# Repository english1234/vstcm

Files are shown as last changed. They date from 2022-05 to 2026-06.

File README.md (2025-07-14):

# VSTCM - the v.st Colour Mod - a colour vector graphics generator
The vstcm is a vector signal transceiver PCB which generates colour vector graphics to be displayed on an oscilloscope or vector monitor such as Amplifone, Wells Gardner WG6100, Hantarex MTRV and Electrohome G05, as used in Star Wars, Tempest, Gravitar, etc. 

When used with a computer (Raspberry Pi, PC, ...) running AdvanceMAME, it can be used to play classic colour (and monochrome) vector arcade games, but it can also play certain games all by itself using various emulators. If you search for vstcm on a well-known video sharing site you can see the board in action.

(Haven't got a vector monitor or an oscilloscope? Make your own, it's not that hard! - see below).

For those who built a V2 of this board, a document is provided to convert the wiring to run with V3 software.

vstcm pcb

starwars

The original v.st was designed by Trammell Hudson for black & white games. Documentation for that version can be found here https://github.com/osresearch/vst and here https://trmm.net/V.st/

Compared to the original version, the new vstcm adds:
- RGB colour with different intensity levels
- 6502, Z80 and 6809 emulators which allows it to play games on its own without a Raspberry Pi or MAME
- A mini version of MAME for playing vector games on the Teensy without a Raspberry Pi
- An upgrade to the Teensy 4.1 for more power (eg >800Mhz as opposed to 120Mhz for the Teensy 3.2)
- Asteroids style test patterns in Red, Green & Blue to aid CRT convergence
- A configuration menu with settings stored on the built in SD card
- Programmable onboard control buttons
- Programmable IR remote control buttons
- Extra pots to control X & Y position (to complement the existing X & Y size pots)
- Several power supply options: either USB, or external 5V/9V/12V

testscreen1

The board was built with simplicity in mind using components that are easy to find, and easy to solder so that anyone can build one.

## Programme code

Currently, the board can work in either of two ways:
- connected to a Raspberry Pi running MAME. The programme code for this option is a development of that which was provided with the original version of the v.st, with modifications made by "Swapfile" (Github user) to interface with AdvanceMAME, and then further modifications made by myself in order to add the new functionality specific to the vstcm, followed by extensive optimisation by fcawth (cf his fork of this project). There is scope for further improvement (see the wiki for this project in the link above), and it is hoped that the publication on github will encourage contributions to develop this as a relatively cheap and easy solution for the vector arcade / vector graphics community.
- on its own, running a 6502, Z80 or 6809 emulator, and with the original game ROM files stored on the SD card of the Teensy. So far, Battlezone, Asteroids and Donkey Kong work with this, but it shouldn't be too much trouble to get others working. Sound and external controls have not been properly implemented as yet (please feel free to contribute the necessary mods to the code...). See instructions below for how to get this to work.

## History of development

For those interested in seeing how things got to this point, the inital development of the PCB was documented with plenty of pictures (in French, but use Google Translate if required) here : https://www.gamoover.net/Forums/index.php?topic=43469.0 (from page 5) and also shows previous work on building vector arcade HV boards, an Amplifone deflection reproduction, an Asteroids game PCB reproduction, a bit of yoke rewinding, etc.

If you want to get in touch to ask questions, or contribute, I can be contacted at: robin@robinchampion.com or on Github (user english1234), Gamoover (english2), UKVAC (english2), KLOV (english2), as well as via the various vector graphics/Vectrex forums on Facebook.

A dedicated vstcm web page can be found here: https://robinchampion.com/vst_colour_mod.htm

Thread on KLOV: https://forums.arcade-museum.com/threads/announcing-the-vstcm-colour-vector-generator.505940/

Thread on UKVAC: http://www.ukvac.com/forum/announcing-the-vstcm-colour-vector-generator_topic388998_page1.html

## Getting the PCB built

A ZIP file is in the Gerbers directory. This can be uploaded to your PCB manufacturer of choice. It's a 2 sided 10cm x 10cm board so should be extremely cheap (JLPCB charged less than 5€ / $5 + shipping for 10 pieces in May 2022).

## Components

The BOM is in a dedicated folder and has Mouser references for many parts at the right hand side. 

- IC2: You need to choose if you are going to use an external supply or not and if so what voltage to use (5V, 9V or 12V). Recom makes these parts, but so do Traco and there may be other brands. Make sure there is a D (for double) at the end of the model number which generates +/- voltages, rather than the S (single) version. See power options below.
- The Molex parts are not strictly necessary, you may prefer something different or simply to solder wires directly to the holes in the PCB.
- U5: See power options below. I have also used a 7805 as a direct replacement with a small heatsink on it, which gets quite warm but hasn't burnt out as yet.
- optional IR remote: I really recommend this if you are putting the board inside a cabinet - see "IR remote programmable control buttons" below.
 
I would recommend socketing everything on the board (Teensy, DACs, Op Amps) so that they can be swapped out if better choices are found in the future.

Make sure you order short resistors, space for them on the board is tight.

## Power options for the PCB

The PCB can be powered in several ways (connect to J6):

|N° | Power supply option | Supplies | C3/C4 | IC2 | U5/C19/C20  | Split pad Teensy | Tested |
|---|---|---|---|---|---|---|---|
| 1 | USB 5V | Complete circuit inc Teensy | Required | RB-0512D | Absent | No | No |
| 2 | USB 5V + external 5V unregulated | USB supplies Teensy, external supplies rest | Required | RB-0512D | Absent | No | Yes |
| 3 | External 9V unregulated | Complete circuit inc Teensy | Required | RB-0912D | Present | Yes | No |
| 4 | External 12V unregulated | Complete circuit inc Teensy | Required | RB-1212D | Present | Yes | Yes |
| 5 | USB 5V + external 12V regulated  | USB supplies Teensy, external supplies rest | Absent | Absent | Absent | No | Yes |

1/ power the whole thing via USB from a Raspberry Pi: This requires a short good quality USB cable to work reliably. Make sure the Pi has at least a 3A supply. Since U5 is absent, bridge the two outer pins with a jumper wire.

2/ power the Teensy via USB from a Raspberry Pi, and use a separate external supply (such as a wall wart) for the DACs and Op Amps. 

3 & 4/ power the whole thing via an external supply which can be 9V or 12V (not 5V): this requires adding a LM2940T-5.0 regulator at U5 along with it's associated caps at C19 & C20, as well as cutting a link on the Teensy to ensure that it doesn't receive conflicting power from both the USB and the external supply. The RB-xx12D needs to be either a 9V or 12V model depending on the voltage of the external supply. A 5V supply won't work as the LM2940 requires over 6V to function according to its datasheet. 

The choice is really just a matter of what you have on hand. It makes no difference what vector CRT you have, as the output voltages of the PCB are the same whatever you use to power it. If you're connecting to an existing arcade machine, then chances are you have a +/-12V supply coming out of the power brick. Otherwise, many people have a box of old "wall wart" 5V (or 9V or 12V) adapters which will work fine: either fit a barrel connector to the PCB input or chop the connector off the end of the power supply and solder the 2 wires directly to the board (check with a multimeter first which is positive and which is ground). 

The easiest option is to use a 5V (option 2) as the LM2940 is not required, and you don't need to cut the link on the Teensy to separate USB and external power.
Do not use J7 unless you have thoroughly understood how the schematic works for the power supply.

## Schematic

This may seem obvious, but it's worth downloading Kicad in order to view the schematic and the PCB as there are some build notes on the schematic, and it will help you to understand the main sections of the PCB and how it all connects together. For the lazier, a PDF is available.

## Programming the Teensy

Follow the instructions on this page to download and install the Arduino environment and Teensyduino extension: https://www.pjrc.com/teensy/td_download.html
Use the Arduino software to load the .ino file in the Teensy code directory.

Connect the Teensy via USB to your computer.

Choose the Teensy 4.1 in the Teensyduino options, and overclock to 816Mhz, as well as the "Fastest" option. Make sure you have the latest version of Teensyduino.

Press the compile button. You may need to add the Bounce2 library if you don't already have it.

Press the upload button (or the button on the Teensy if it doesn't upload automatically).

(You can also use PlatformIO if you prefer).

There is a more detailed guide "How to programme the Teensy with the code for the VSTCM PCB.pdf" in the root directory.

## Testing the vstcm

Once the board is built and the Teensy programmed and fitted, it can be connected to your deflection board of choice (it has been tested on Amplifone, Wells Gardner WG6100, Electrohome G05 and Hantarex MTRV so far) and when powered on should show a test screen. It may be necessary to change the size and positions pots on the PCB as well as other controls on the deflection board (such as Z or colour gain).

Before connecting to the deflection board, it would probably be a good idea to make sure the vstcm is generating appropriate voltages at its outputs (preferably with an oscilloscope, or failing that with a decent multimeter). 

If you want to save changes to settings shown on the onscreen menu, then put a SD card in the Teensy (formatted with FAT32). After changing the settings to your requirements and pressing the middle button on the PCB, the vstcm.ini file will be created at the root of the SD card so that they can be reloaded at each boot. 

typicalsetup

## Testing Battlezone with the 6502 emulator

Put the following ROM files on a SD card in a directory called roms/Battlezone: 036414a.01, 036413.01, 036412.01, 036411.01, 036410.01, 036409.01, 036422.01, 036421.01 (it's up to you to find them from somewhere...).

Put the SD card in the slot on the Teensy.

Upload the bzone.ino to the vstcm using the Arduino software.

Plug it in.

Switch on! 

If you have a IR remote then you can control the game in a rather basic manner for the moment... (press OK to start)

## Testing games with AdvanceMAME

A Raspberry Pi 4 or 400 is recommended (I have also tested with a Pi 3 Model B+ 2017 and an Orange Pi 3 LTS which seem to work ok too). If you are running the vstcm from the Raspberry/Orange Pi then a 3A supply would be preferable.
Other options are Windows, a Linux VM under Windows, native Linux or Mac (the latter of which I have not yet tested). 
I followed the instructions here to download and compile AdvanceMAME: https://www.arcade-projects.com/threads/almost-pixel-perfect-arcade-emulation-on-raspberry-pi-with-advancemame.7777/

orangepi

Basically, there are just 7 commands on the Pi which are as follows:

```sudo apt-get install git autoconf automake libsdl2-dev libasound2-dev libfreetype6-dev zlib1g-dev libexpat1-dev libslang2-dev libncurses5-dev

git clone https://github.com/amadvance/advancemame.git

cd advancemame

sh autogen.sh

./configure

make -j3

sudo make install
```

You need to find some ROMs from somewhere and copy them into the ROM folder. I'm sure you'll manage to find them... The easiest way to get them on to the Pi is to set up a Samba share and copy them over from a PC.

Then to launch, type advmame followed by the name of the game.

If you're not getting output over the USB cable to the vstcm, then check the advmame.rc file and at the bottom make sure you have vector_aux_renderer set to dvg (instead of none) and vector_aux_renderer_port set to /dev/ttyACM0

gravitartempest

The AdvanceMAME protocol for the USB DVG is here: https://github.com/amadvance/advancemame/blob/master/advance/osd/dvg.c 

You can change the settings on the VSTCM during a game by pressing the left and right buttons on the PCB simultaneously to display the menu as an overlay.

## IR remote programmable control buttons

For £1 / $1 / 1€ you can get a HX1838 infra red adapter board with remote control, wiring, everything you need in fact. There are only 3 wires to connect: 5V, GND and signal. I soldered pin headers in the holes provided on either side of the Teensy, and put 5V on the bottom left hand hole of the Teensy (to left of USB socket), GND on the bottom right pin of the Teensy, and signal on pin 32 (top right hand pin of Teensy). 

This might seem like a bit of a gadget, but when you are spending your time going behind the arcade cab to press a button, coming back round the front to see the effect on the screen, and doing this over and over again, the advantages become obvious! 

The IR sensor is the size of an LED and so very easy to hide somewhere at the front of an arcade cab, and then you can just change the settings at will while you look at the screen.

IR1ir2

## Haven't got a vector monitor or an oscilloscope?

Apart from this PCB, you need a CRT, a high voltage board, a deflection board and a power supply to make a complete vector monitor. There are solutions for all of these parts:

CRT - I'm using a 19"/48cm Philips TV bought for pennies through the small ads. You need to rewind the yoke using magnet wire. There is an excellent video by Jason Kopp here which explains all: https://youtu.be/Ci9qiGVMF7s I experimented on a 5" b&w security monitor first, then went for the big screen. Avoid Trinitrons and PC monitors, you need a basic no frills TV tube. It took me several attempts to get it more or less right, but I still have some wires which are not completely straight and the result seems to be the slightly bent vectors visible in the top right hand corner of my screen in the photo of the test screen above. The whole thing really wasn't hard, it just requires patience.

High voltage: Amplifone and Wells Gardner 6100 blank PCBs are available online, and there are also fully built solutions (see the various vector groups on Facebook) available new or second hand from the usual auction sites and specialist arcade sellers (mostly USA based).

Deflection board: I bought a second hand non working Amplifone and then fixed it (which wasn't hard, plenty of info online), but new PCBs are available online, and a Wells Gardner WG6100 should work too.

Power supply: the CRT and deflection board can be run either from an old Atari power brick, or else by wiring together two cheap 24V power supplies from Aliexpress in order to provide +/- 24V which satisfies the requirement for 50VAC on a Amplifone colour vector monitor. The CRT needs 6.3V for the heater filament, which I'm getting from an Atari power brick using the supply meant for the coin door, but there are other solutions if you look online (hint: 6.3V is frequently required for valve amp projects). If you find the right Atari power brick, it will power the whole thing: CRT, HV, deflection, Raspberry Pi and vstcm.

There's plenty of discussion of solutions to these problems on KLOV, UKVAC, and the FB vector forums with plenty of knowledgeable people able to answer questions. Also there are a fair few videos on Youtube going from theory to practice. Again, it's not that hard, so give it a go!

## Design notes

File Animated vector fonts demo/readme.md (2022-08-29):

Found this here: https://forum.pjrc.com/threads/45016-Vector-Font-library-for-Teensy-3-6

and associated video showing the code running on a LCD here: https://youtu.be/T0WgGcm7ujM

and adapted it for the VSTCM V3.0

here it is running on a vector monitor using the vstcm and Teensy 4.1 https://youtu.be/WIkLRix-tPs

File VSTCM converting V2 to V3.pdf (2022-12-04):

# VSTCM

# Converting PCB V2 to V3

Several improvements have been made in the change from VSTCM V2 to V3, in order to increase performance and improve image quality.

One of the changes made for much improved performance is a modification of the DAC outputs. This change means that code developed for V3 no longer works on V2 and vice versa. However, it is easy to implement the change on a V2 PCB.

To convert the DAC outputs of a PCB V2, two tracks need to be cut, and two patch wires added.

The third difference (X & Y outputs swapped) can be changed in the VSTCM settings (Swap XY).

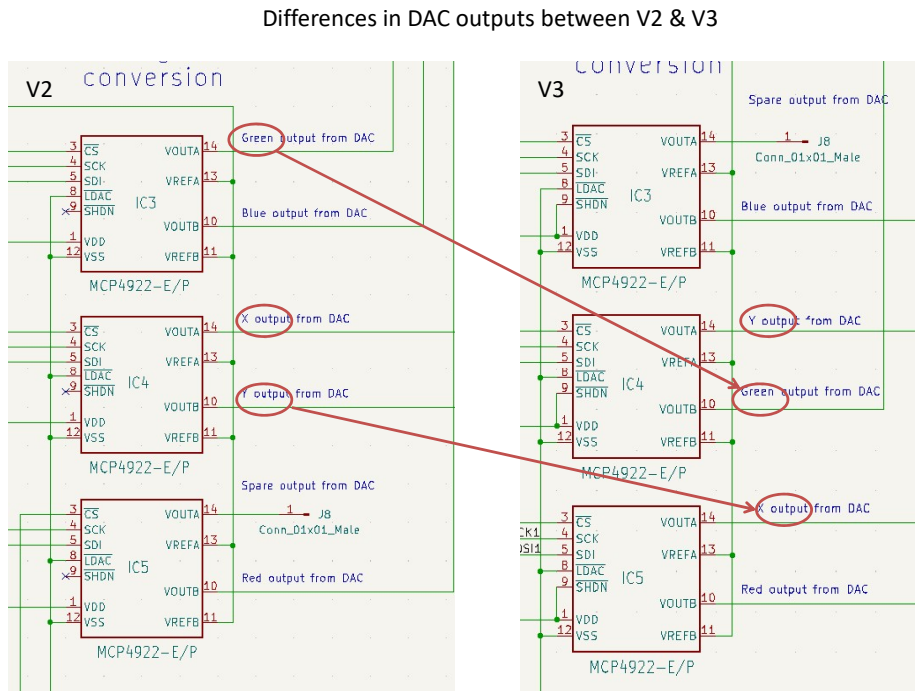
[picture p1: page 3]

Differences in DAC outputs between V2 & V3

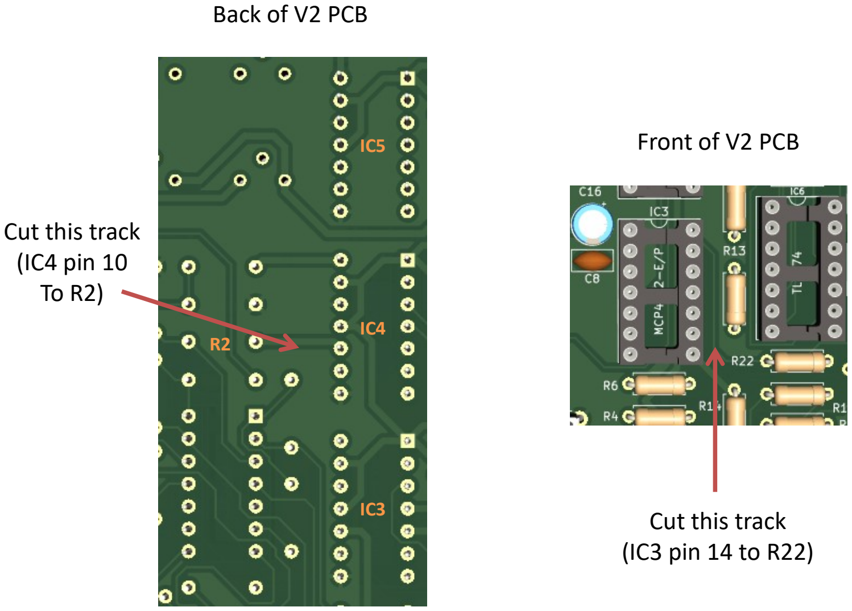
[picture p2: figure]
Back of V2 PCB; Front of V2 PCB; Cut this track (IC4 pin 10 To R2); Cut this track (IC3 pin 14 to R22)

Back of V2 PCB

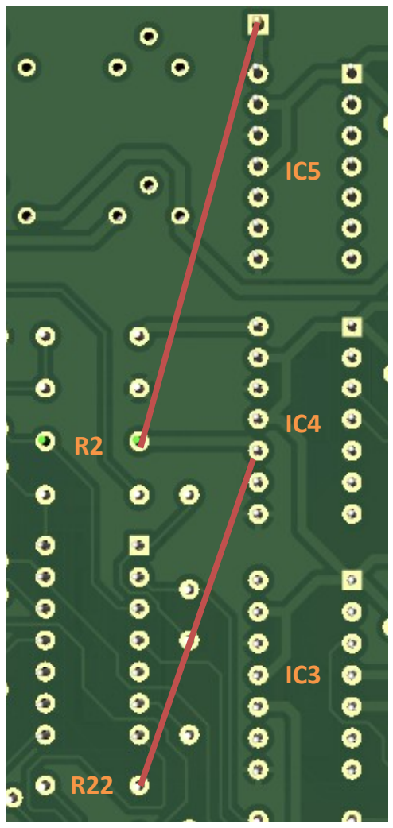
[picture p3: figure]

Add patch wire from
J8 to R2

Add patch wire from
IC4 pin 10 to R22

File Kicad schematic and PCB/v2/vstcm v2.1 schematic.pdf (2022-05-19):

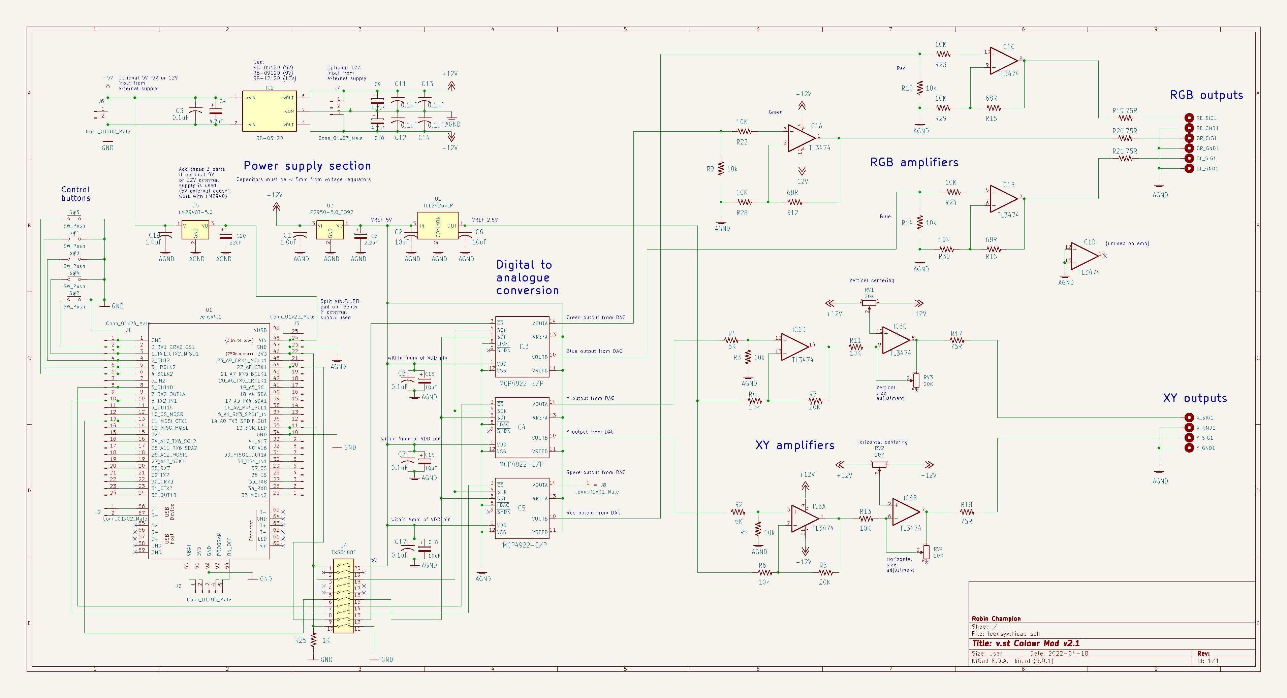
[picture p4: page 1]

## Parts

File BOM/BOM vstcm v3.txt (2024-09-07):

| Ref | Qty  | Value | Component name | Footprint | Mouser Ref | 
| --- | ---- | --- | --- | --- | --- |
| C1, C19 (optional) |  2 | 1.0uF 50v CER | C-US025-024X044 | Capacitor_THT:C_Disc_D5.0mm_W2.5mm_P2.50mm | C420C105K5R5TA7200 | 
| C2, C6, C27 |  3 | 10uF 25V CER | C-US025-024X044 | Capacitor_THT:C_Disc_D5.0mm_W2.5mm_P2.50mm | FG26X7R1E106KRT06 | 
| C22, C12, C7, C24, C3, C17, C23, C21 | | | | | |
| C26, C13, C8, C25, C11, C14 | 14 | 0.1uF 50V CER | C-US025-024X044 | Capacitor_THT:C_Disc_D5.0mm_W2.5mm_P2.50mm | C410C104Z5U5TA7200 | 
| C4, C9, C10 |  3 | 4.7uF50V | CP_Radial_D5.0mm_P2.00mm | Polarized capacitor | ESH475M050AC3AA | 
| C5 |  1 | 2.2uF 50V | CP_Radial_D5.0mm_P2.00mm | Polarized capacitor | ESH225M050AC3AA | 
| C15, C16, C18 |  3 | 10uF 50V | CP_Radial_D5.0mm_P2.00mm | Polarized capacitor | ESH106M050AC3AA | 
| C20 (optional) |  1 | 22uF 50V | CP_Radial_D5.0mm_P2.00mm | Polarized capacitor | ESH226M050AC3AA |
| IC1, IC6 |  2 | TL3474 | QUAD_OPAMPP | DIP-14_W7.62mm_Socket | TL3474IN | 
| IC2 |  1 | 5VDC | DC/DC CONVERTER +/-5V 1W | RECOM / Traco | RB-0512D | 
| IC2 (optional) |  1 | 9VDC | DC/DC CONVERTER +/-12V 1W| RECOM / Traco | RB-0912D | 
| IC2 (optional) |  1 | 12VDC | DC/DC CONVERTER +/-12V 1W| RECOM / Traco | RB-1212D | 
| IC3, IC4, IC5 |  3 | MCP4922-E/P | MCP4922-E/P | DIP-14_W7.62mm_Socket | MCP4922-E/P | 
| J1 |  1 | Conn_01x24_Male | Conn_01x24_Male | Generic connector, single row, 01x24 | | 
| J2 |  1 | Conn_01x05_Male | Conn_01x05_Male | Connector_PinHeader_2.54mm:PinHeader_1x05_P2.54mm_Vertical | | 
| J3 |  1 | Conn_01x25_Male | Conn_01x25_Male | Generic connector, single row, 01x25Aliexpress | | 
| J5 |  1 | Conn_01x06_Male | Conn_01x06_Male | Connector_PinHeader_2.54mm:PinHeader_1x06_P2.54mm_Vertical | | 
| J6 |  1 | Conn_01x02_Male | Conn_01x02_Male | Molex 22-27-2021Generic connector, single row, 01x02 | 22-27-2021 | 
| | | | | Molex 10-11-20232 pin plug connector for 22-27-2021 | 10-11-2023 | 
| J7 |  1 | Conn_01x03_Male | Conn_01x03_Male | Molex 38-00-6293Generic connector, single row, 01x03 | 38-00-6293 | 
| |  1 | | | Molex 22-01-20373 pin plug connector for 38-00-6293 | 22-01-2037 | 
| | | | | Pins for Molex connectors series 7879 | | 
| J8 |  1 | Conn_01x01_Male | Conn_01x01_Male | Connector_PinHeader_2.54mm:PinHeader_1x01_P2.54mm_Vertical | | 
| J9 |  1 | Conn_01x02_Male | Conn_01x02_Male | Generic connector, single row, 01x02Aliexpress | | 
| TP1, TP3, TP2 |  3 | Conn_01x01_Male | Conn_01x01_Male | Connector_PinHeader_2.54mm:PinHeader_1x01_P2.54mm_Vertical | | 
| R11, R13 |  2 | 5K 1% 1/4W | R-US_0204/2V | Resistor_THT:R_Axial_DIN0207_L6.3mm_D2.5mm_P7.62mm_Horizontal | 603-CFR25SJT-52-5K |
| R4, R5, R25, R14, R3, R26, R9, R6, R10 | | | | | |
| R23, R24, R8, R27, R29, R7, R22, R31 | | | | | |
| R28, R30 | 19 | 10K 1% 1/4W | R-US_0204/2V | Resistor_THT:R_Axial_DIN0207_L6.3mm_D2.5mm_P7.62mm_Horizontal | 71-RN60E1002F |
| R12, R15, R16 |  3 | 15K 1% 1/4W | R-US_0204/2V | Resistor_THT:R_Axial_DIN0207_L6.3mm_D2.5mm_P7.62mm_Horizontal | 71-CCF5515K0FKE36 |
| R17, R18, R19, R20, R21 |  5 | 75R 5% 1/4W CARB| R-US_0204/7 | Resistor_THT:R_Axial_DIN0207_L6.3mm_D2.5mm_P7.62mm_Horizontal | CFR-25JB-52-75R | 
| R1, R2 |  2 | 1K 1/3W 5% CARB | R-US_0204/2V | Resistor_THT:R_Axial_DIN0207_L6.3mm_D2.5mm_P7.62mm_Horizontal | CFR25J1K0 | 
| RV1, RV2, RV3, RV4 |  4 | 20K | R_Potentiometer | Potentiometer_THT:Potentiometer_Bourns_3386P_Vertical | 3386P-1-203LF | 
| SW1, SW2, SW3, SW4, SW5 |  5 | SW_Push | SW_Push | SW_PUSH_6mm_H4.3mm Push button switch, generic, two pins | TS02-66-80-BK-100-SCR-D | 
| U1 |  1 | Teensy4.1 | | | DEV-16771 | 
| U3 |  1 | LP2950-3.3_TO92 | LP2950-3.3_TO92 | Micropower Voltage Reg with Shutdown 100mA Fixed Output 3.3V  | 926-2950CZ-3.3/NOPB | 
| U5 (optional) |  1 | LM2940T-5.0 | | REG LINEAR 5V 1A TO220-3 | | 
| L1 |  1 | 0R | Wire link | | |
| Optional |  1 | HX1838 | | IR Remote control and sensor | Aliexpress |
| BL_GND1, Y_GND1, RE_SIG1, RE_GND1 | | | | | |
| Y_SIG1, BL_SIG1, GR_SIG1, X_SIG1 | | | | | |
| GR_GND1,X_GND1 |  2 | .156 SPOX | 5 pin male Molex | Molex connector 09-65-2058 (or use 1x10 pin) | 538-09-65-2058 |
| Teensy 4.1 |  1 | | | Attach pin headers to plug into PCB | Various sources |
| IC sockets |  5 | | | DIP 14 pitch 2.54mm, row spacing 7.62mm | 571-1-2199298-3 |
| Mounting for Teensy | | | | Use breakable 40 pin headers and sockets | Aliexpress |

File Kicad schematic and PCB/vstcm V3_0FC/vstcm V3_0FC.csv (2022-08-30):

Id | Designator | Package | Quantity | Designation | Supplier and ref
1 | BL_GND1,Y_GND1,RE_SIG1,RE_GND1,Y_SIG1,BL_SIG1,GR_SIG1,X_SIG1,GR_GND1,X_GND1 | Molex156Pin | 10 | MountingHole_Pad
2 | IC4,IC3,IC5 | DIP-14_W7.62mm_Socket | 3 | MCP4922-E/P
3 | U5 | TO-220-3_Vertical | 1 | LM2940T-5.0
4 | R15,R16,R12 | R_Axial_DIN0207_L6.3mm_D2.5mm_P7.62mm_Horizontal | 3 | 15K
5 | SW2,SW4,SW5,SW1,SW3 | SW_PUSH_6mm_H4.3mm | 5 | SW_Push
6 | R21,R17,R20,R19,R18 | R_Axial_DIN0207_L6.3mm_D2.5mm_P7.62mm_Horizontal | 5 | 75R
7 | RV1,RV4,RV3,RV2 | Potentiometer_Bourns_3386P_Vertical | 4 | 20K
8 | R4,R5,R25,R14,R3,R26,R9,R6,R10 | R_Axial_DIN0207_L6.3mm_D2.5mm_P7.62mm_Horizontal | 9 | 10k
9 | C18,C15,C16 | CP_Radial_D5.0mm_P2.00mm | 3 | 10uF
10 | C22,C12,C7,C24,C3,C17,C23,C21,C26,C13,C8,C25,C11,C14 | C_Disc_D5.0mm_W2.5mm_P2.50mm | 14 | 0.1uF
11 | R24,R23,R8,R27,R29,R7,R22,R31,R28,R30 | R_Axial_DIN0207_L6.3mm_D2.5mm_P7.62mm_Horizontal | 10 | 10K
12 | R11,R13 | R_Axial_DIN0207_L6.3mm_D2.5mm_P7.62mm_Horizontal | 2 | 5K
13 | C2,C27,C6 | C_Disc_D5.0mm_W2.5mm_P2.50mm | 3 | 10uF
14 | C4,C10,C9 | CP_Radial_D5.0mm_P2.00mm | 3 | 4.7uF
15 | TP1,TP3,J8,TP2 | PinHeader_1x01_P2.54mm_Vertical | 4 | Conn_01x01_Male
16 | C20 | CP_Radial_D5.0mm_P2.00mm | 1 | 22uF
17 | J7 | Molex_KK-254_AE-6410-03A_1x03_P2.54mm_Vertical | 1 | Conn_01x03_Male
18 | IC1,IC6 | DIP-14_W7.62mm_Socket | 2 | TL3474
19 | J1 | PinHeader_1x24_P2.54mm_Vertical | 1 | Conn_01x24_Male
20 | J9 | PinHeader_1x02_P2.54mm_Vertical | 1 | Conn_01x02_Male
21 | R1,R2 | R_Axial_DIN0207_L6.3mm_D2.5mm_P7.62mm_Horizontal | 2 | 1K
22 | C5 | CP_Radial_D5.0mm_P2.00mm | 1 | 2.2uF
23 | J6 | Molex_KK-254_AE-6410-02A_1x02_P2.54mm_Vertical | 1 | Conn_01x02_Male
24 | U3 | TO-92 | 1 | LP2950-3_3_TO92
25 | C1,C19 | C_Disc_D5.0mm_W2.5mm_P2.50mm | 2 | 1.0uF
26 | J3 | PinHeader_1x25_P2.54mm_Vertical | 1 | Conn_01x25_Male
27 | L1 | L_Axial_L12.0mm_D5.0mm_P15.24mm_Horizontal_Fastron_MISC | 1 | L
28 | U1 | Teensy41 | 1 | Teensy4.1
29 | IC2 | RECOM_0512D | 1 | RB-0512D
30 | J2 | PinHeader_1x05_P2.54mm_Vertical | 1 | Conn_01x05_Male

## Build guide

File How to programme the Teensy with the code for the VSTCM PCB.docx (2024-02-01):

How to programme the Teensy with the code for the VSTCM PCB

1/ Download the code from Github and unzip it.

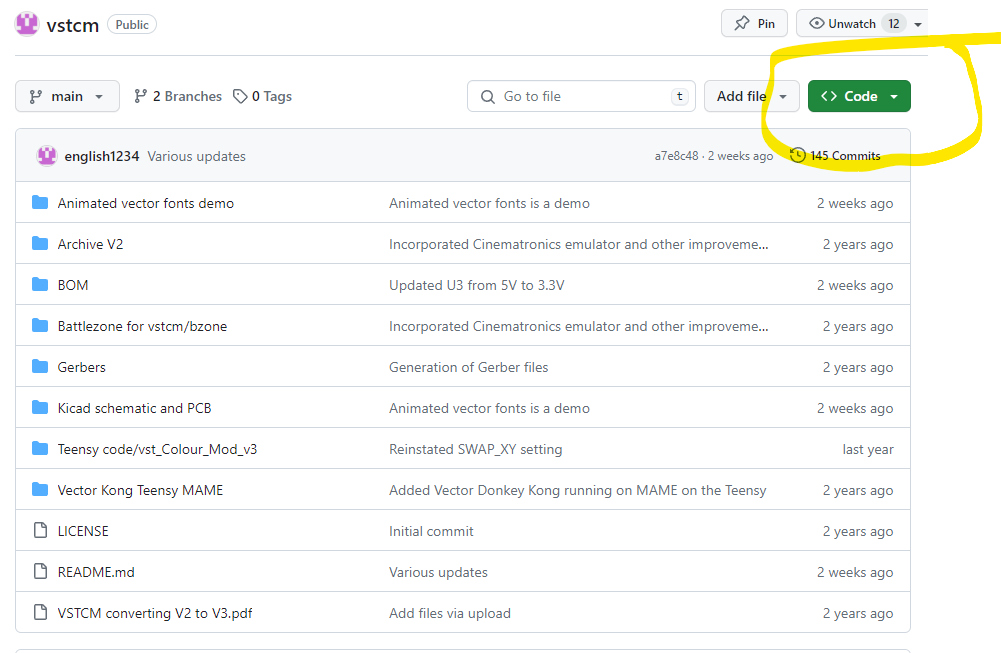
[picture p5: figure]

2/ Open Arduino IDE

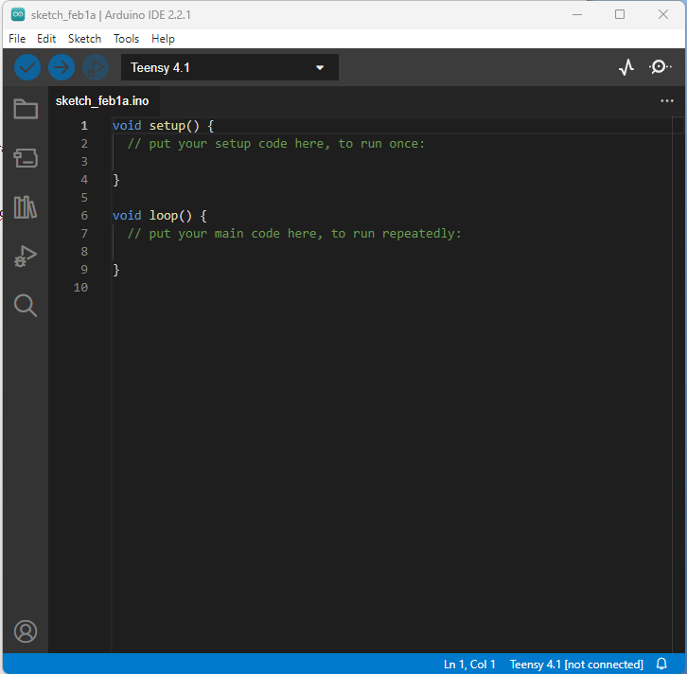
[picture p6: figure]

Open vst_Colour_Mod_v3 .ino (File->Open…) in the Teensy code directory of the unzipped directory.

Make sure the Teensy 4.1 board is selected, and set the code to “Fastest” and 816Mhz.

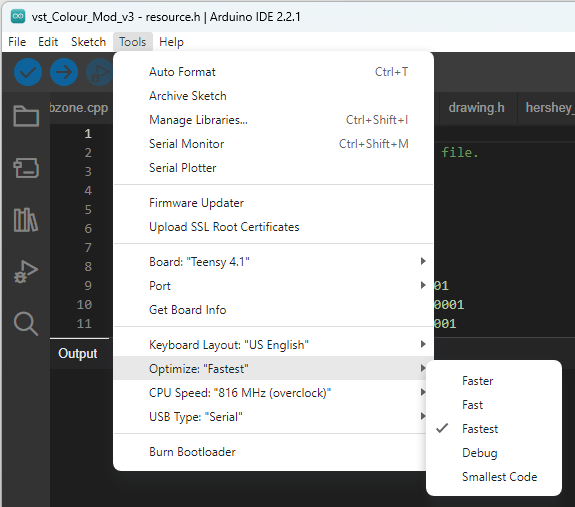
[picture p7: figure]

Connect the Teensy with a USB cable to the PC. Press the blue circle with a tick (check) to compile the sketch.

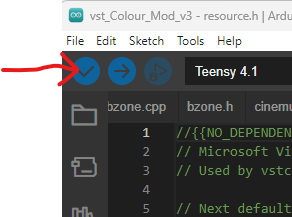
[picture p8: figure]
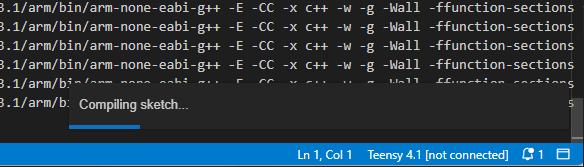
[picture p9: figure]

If the sketch compiles correctly (there might be missing libraries to sort out), the following screen should appear (it may be an icon on the task bar)

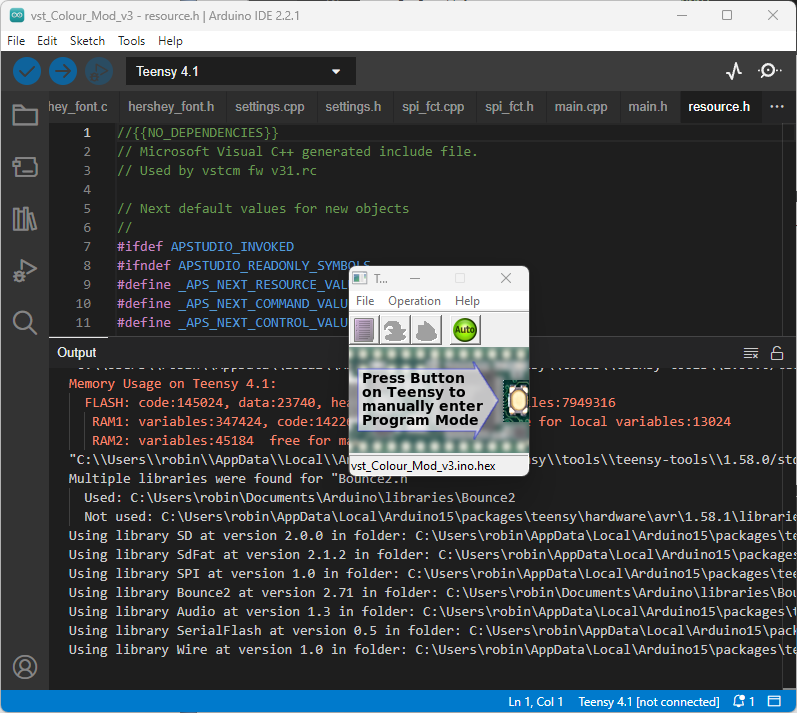
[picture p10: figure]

Press the white button on the Teensy to upload the code. It is now programmed and can be disconnected and is ready for use.

Once the VSTCM is powered up and connected to a vector monitor or oscilloscope, the menu screen should display.

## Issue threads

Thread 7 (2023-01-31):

L1 purpose?

pashdown, 2023-01-31:
L1 is marked as optional on the BOM, but there is no documentation as to why, or how the value is calculated (100uF / 220uF).  Can someone clarify this?

english1234, 2023-01-31:
It was added as an experiment on the v3 by @fcawth, but it had no visible effect as far as I'm aware, so can be left out: just bridge it with wire.

Closed 2023-04-04.

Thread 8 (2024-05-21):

Pincushion and linearity

smdjeff, 2024-05-21:
https://github.com/english1234/vstcm/blob/8db37865ba3121a6b98a831275f08750b0315600/Teensy%20code/vst_Colour_Mod_v3/drawing.cpp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

Some vector games have linearity and pincushion in the deflection board, some are on the game boards.

Consider adding linearity.
Consider making them adjustable values, not just on / off.

english1234, 2024-05-21:
Thanks for the suggestion Jeff, I've added it to the wiki which contains ideas for future versions. If you want to incorporate the changes yourself, then I'd be happy to integrate them.

Closed 2024-05-21.

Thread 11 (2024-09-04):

Divide power connector requirements, L1, add sockets, and female molex on BOM

pashdown, 2024-09-04:
It is somewhat unclear as to what components are required for what style of power inputs, could this be clarified?  L1 shows a resistor, which I presume is used instead of IR, what is it? Could the sockets for the ICs and Teensy be on the BOM, along with the female molex connector that matches 09-65-2058?

pashdown, 2024-09-06:
Thank you for doing this.  My confusion on the sockets is that Mouser seems to have a billion different types of DIP 14 and I don't know what the spec is for the Teensy.

english1234, 2024-09-07:
For DIP 14 the requirement is pitch of 2.54mm and row spacing of 7.62mm. I have updated the BOM with suggested Mouser references. For the Teensy I just used pin headers and sockets, which you can buy in breakable strips of 40 pins. Mouser ones seem very expensive, I get them in packs from Aliex or Amazon.

Closed 2024-11-11.

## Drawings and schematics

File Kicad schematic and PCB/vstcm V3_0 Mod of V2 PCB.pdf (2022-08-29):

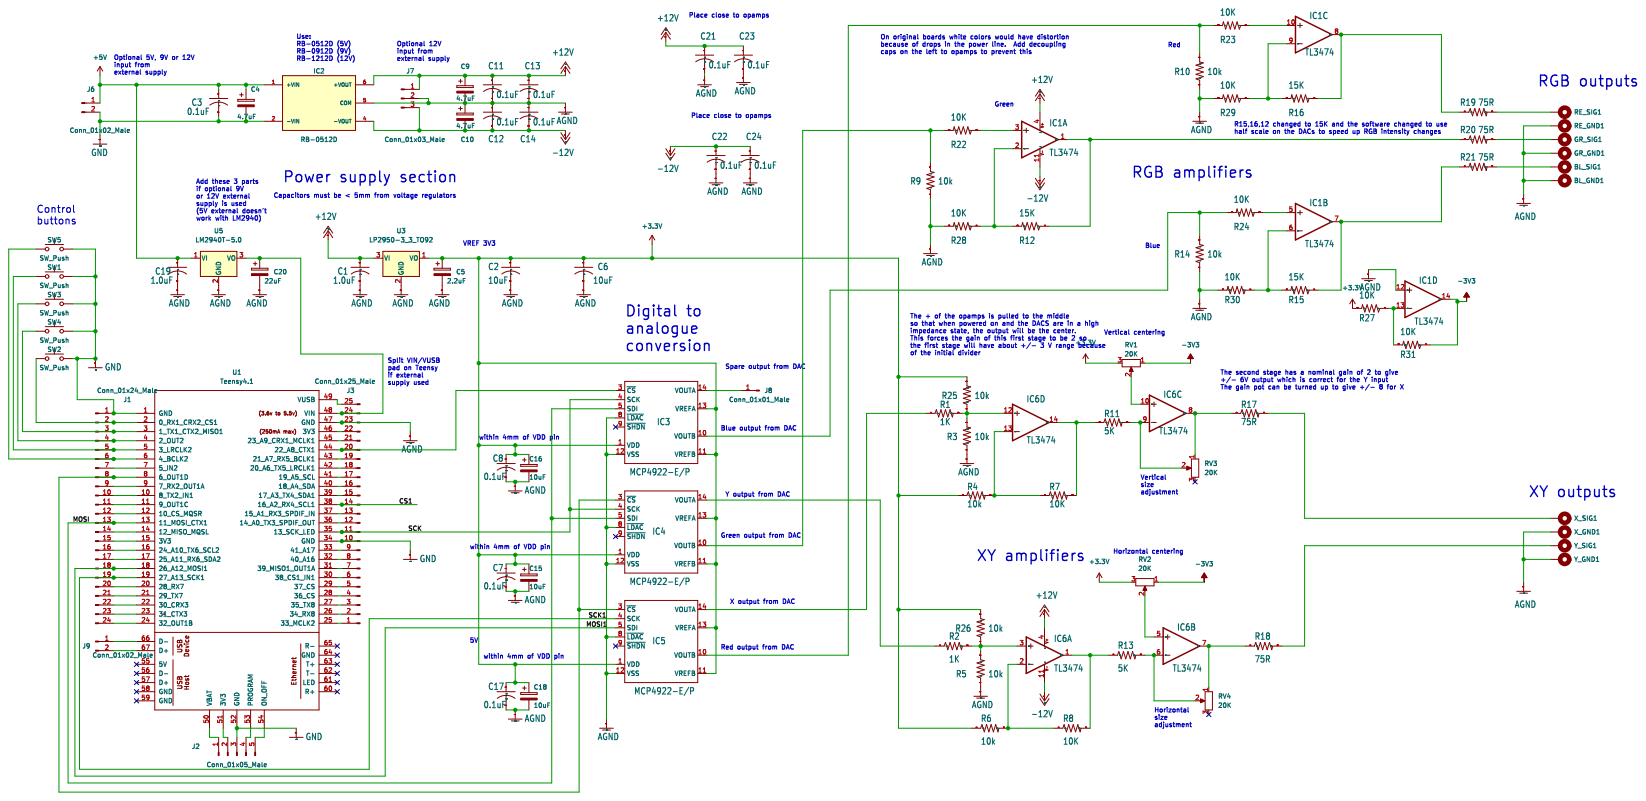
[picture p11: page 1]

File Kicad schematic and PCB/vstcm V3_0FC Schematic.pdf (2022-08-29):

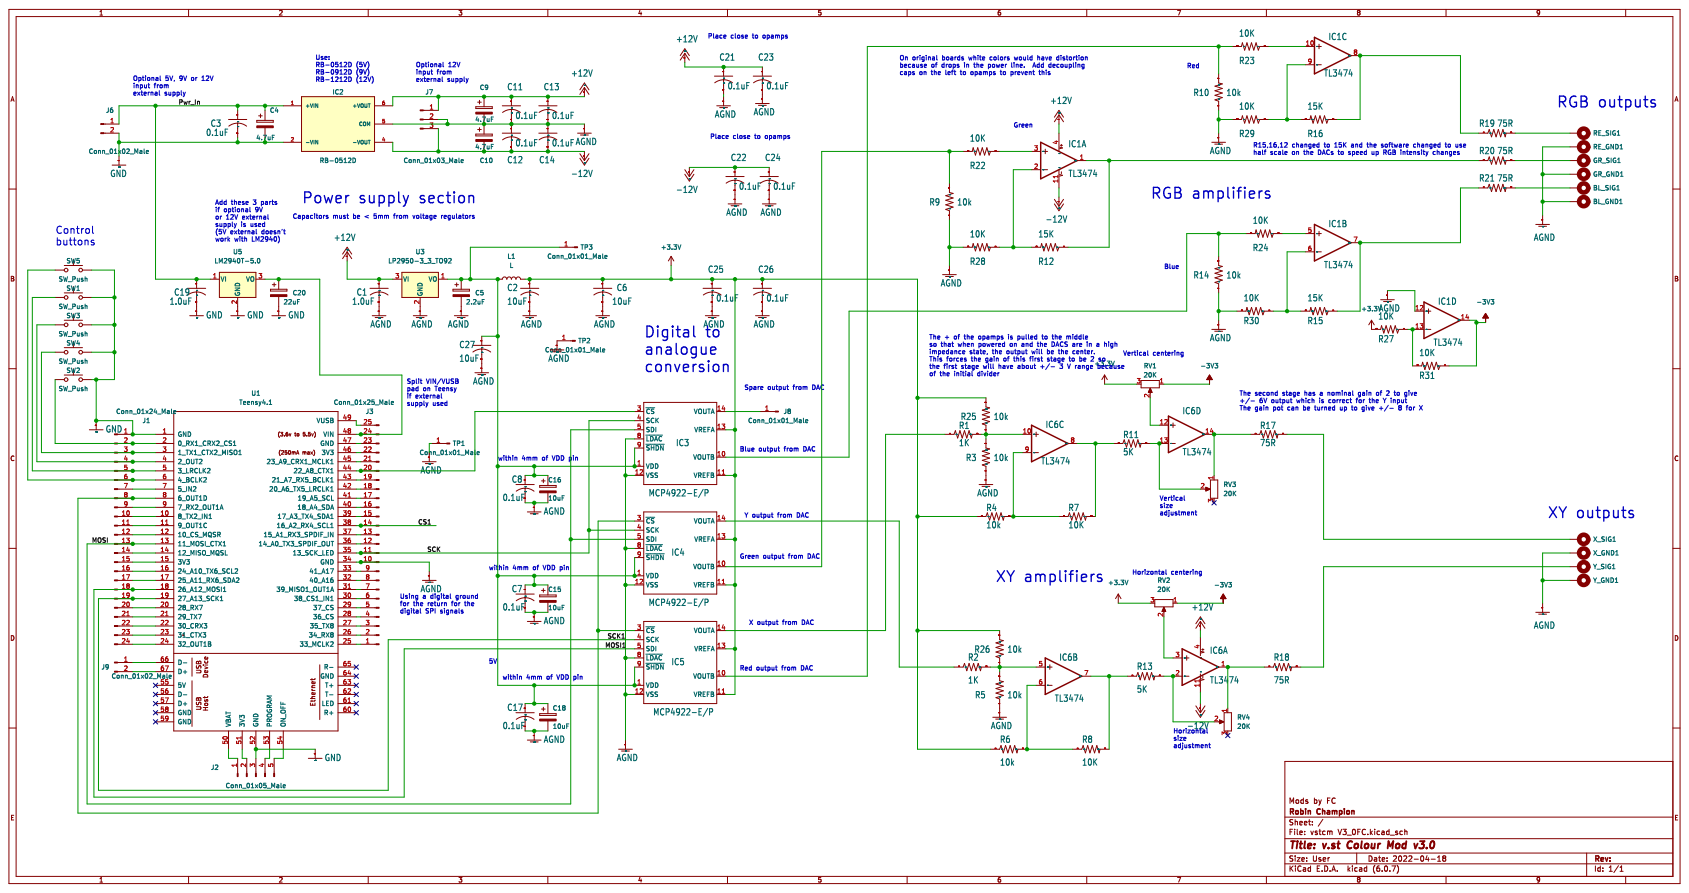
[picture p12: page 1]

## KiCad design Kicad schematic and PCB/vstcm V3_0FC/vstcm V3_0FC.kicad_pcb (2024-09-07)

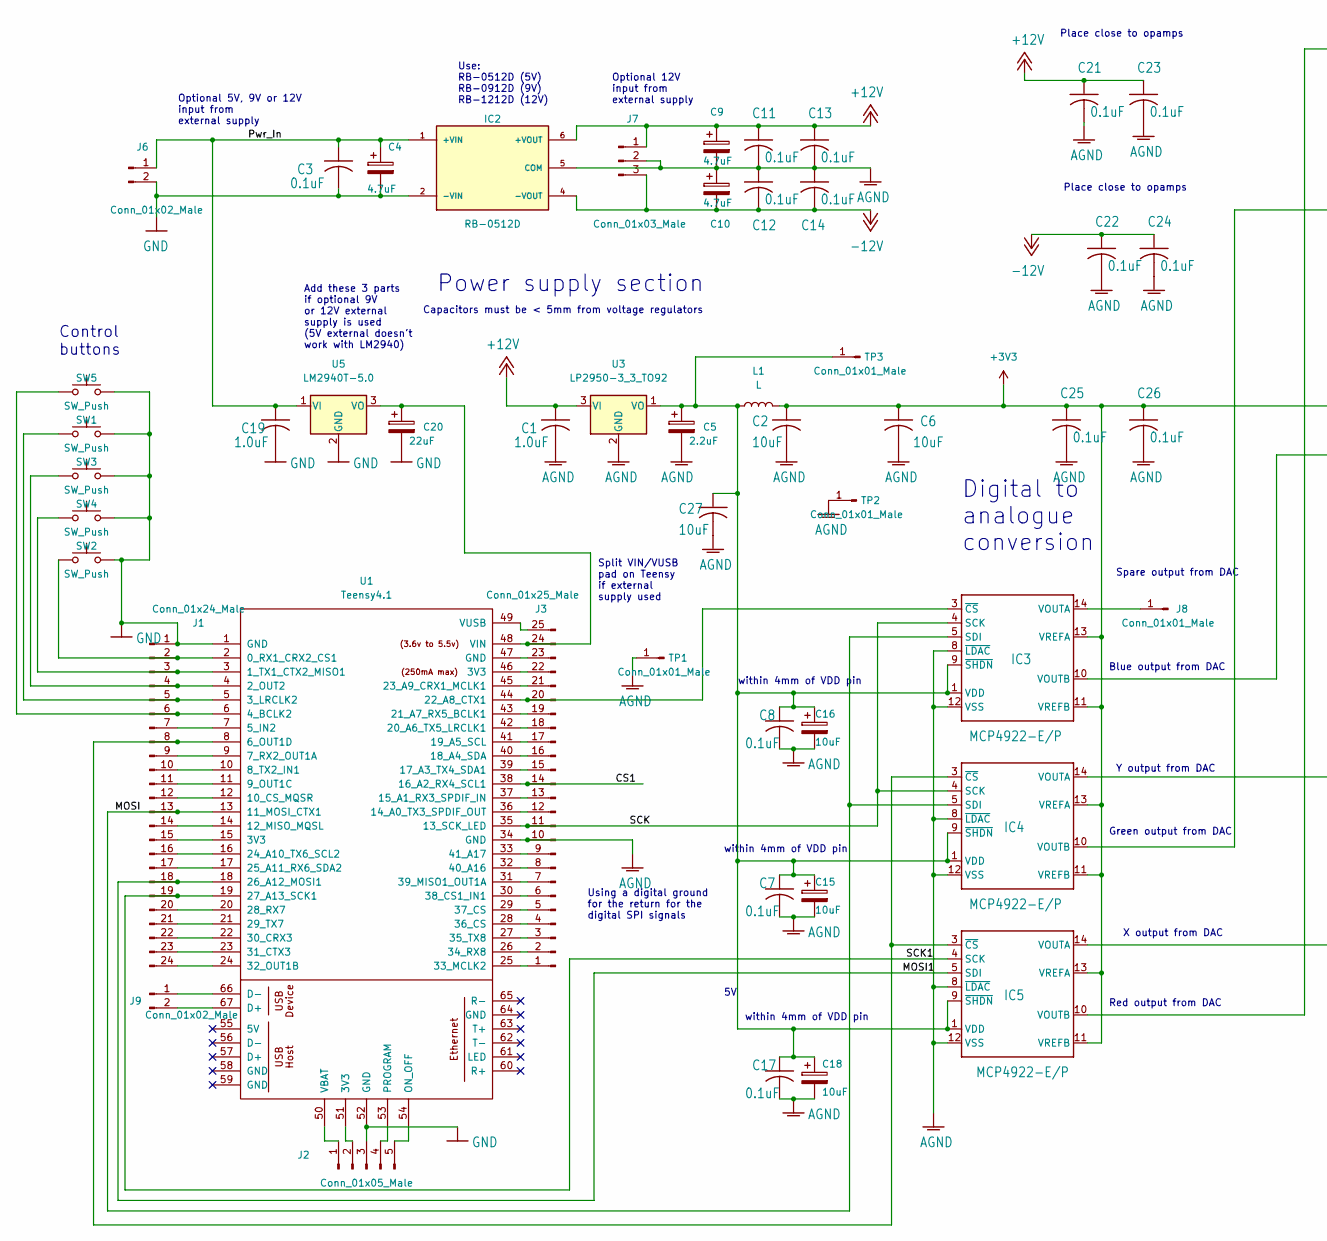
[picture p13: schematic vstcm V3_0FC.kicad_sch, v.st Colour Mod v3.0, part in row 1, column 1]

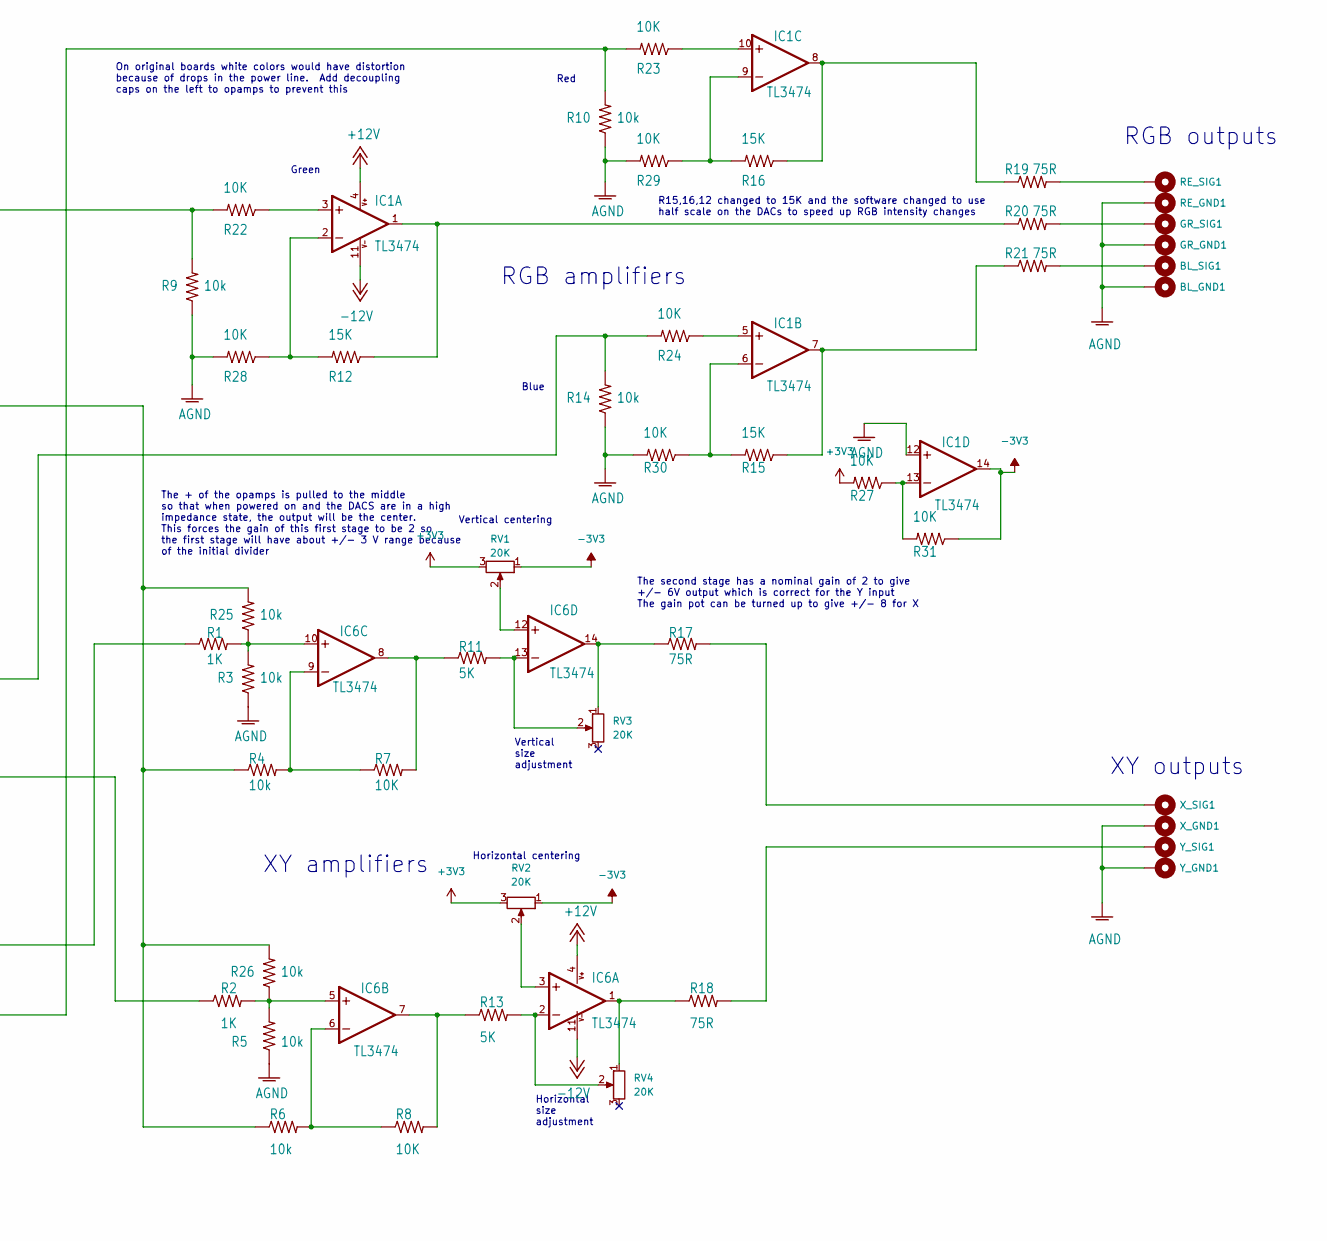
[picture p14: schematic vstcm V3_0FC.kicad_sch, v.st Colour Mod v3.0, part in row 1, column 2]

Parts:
BL_GND1: MountingHole_Pad; MountingHole_2.2mm_M2_DIN965_Pad_TopBottom
BL_SIG1: MountingHole_Pad; MountingHole_2.2mm_M2_DIN965_Pad_TopBottom
C1, C19: 1.0uF; C_Disc_D5.0mm_W2.5mm_P2.50mm
C2, C6, C27: 10uF; C_Disc_D5.0mm_W2.5mm_P2.50mm
C3, C7, C8, C11, C12, C13, C14, C17, C21, C22, C23, C24, C25, C26: 0.1uF; C_Disc_D5.0mm_W2.5mm_P2.50mm
C4, C9, C10: 4.7uF; CP_Radial_D5.0mm_P2.00mm
C5: 2.2uF; CP_Radial_D5.0mm_P2.00mm
C15, C16, C18: 10uF; CP_Radial_D5.0mm_P2.00mm
C20: 22uF; CP_Radial_D5.0mm_P2.00mm
GR_GND1: MountingHole_Pad; MountingHole_2.2mm_M2_DIN965_Pad_TopBottom
GR_SIG1: MountingHole_Pad; MountingHole_2.2mm_M2_DIN965_Pad_TopBottom
IC1, IC6: TL3474; DIP-14_W7.62mm_Socket
IC2: RB-0512D; RECOM_0512D; PARTREV 0/2015
IC3, IC4, IC5: MCP4922-E/P; DIP-14_W7.62mm_Socket
J1: Conn_01x24_Male; PinHeader_1x24_P2.54mm_Vertical
J2: Conn_01x05_Male; PinHeader_1x05_P2.54mm_Vertical
J3: Conn_01x25_Male; PinHeader_1x25_P2.54mm_Vertical
J6: Conn_01x02_Male; Molex_KK-254_AE-6410-02A_1x02_P2.54mm_Vertical
J7: Conn_01x03_Male; Molex_KK-254_AE-6410-03A_1x03_P2.54mm_Vertical
J8: Conn_01x01_Male; PinHeader_1x01_P2.54mm_Vertical
J9: Conn_01x02_Male; PinHeader_1x02_P2.54mm_Vertical
L1: L; L_Axial_L12.0mm_D5.0mm_P15.24mm_Horizontal_Fastron_MISC
R1, R2: 1K; R_Axial_DIN0207_L6.3mm_D2.5mm_P7.62mm_Horizontal
R3, R4, R5, R6, R9, R10, R14, R25, R26: 10k; R_Axial_DIN0207_L6.3mm_D2.5mm_P7.62mm_Horizontal
R7, R8, R22, R23, R24, R27, R28, R29, R30, R31: 10K; R_Axial_DIN0207_L6.3mm_D2.5mm_P7.62mm_Horizontal
R11, R13: 5K; R_Axial_DIN0207_L6.3mm_D2.5mm_P7.62mm_Horizontal
R12, R15, R16: 15K; R_Axial_DIN0207_L6.3mm_D2.5mm_P7.62mm_Horizontal
R17, R18, R19, R20, R21: 75R; R_Axial_DIN0207_L6.3mm_D2.5mm_P7.62mm_Horizontal
RE_GND1: MountingHole_Pad; MountingHole_2.2mm_M2_DIN965_Pad_TopBottom
RE_SIG1: MountingHole_Pad; MountingHole_2.2mm_M2_DIN965_Pad_TopBottom
RV1, RV2, RV3, RV4: 20K; Potentiometer_Bourns_3386P_Vertical
SW1, SW2, SW3, SW4, SW5: SW_Push; SW_PUSH_6mm_H4.3mm
TP1, TP2, TP3: Conn_01x01_Male; PinHeader_1x01_P2.54mm_Vertical
U1: Teensy4.1; Teensy41
U3: LP2950-3_3_TO92; TO-92
U5: LM2940T-5.0; TO-220-3_Vertical
X_GND1: MountingHole_Pad; MountingHole_2.2mm_M2_DIN965_Pad_TopBottom
X_SIG1: MountingHole_Pad; MountingHole_2.2mm_M2_DIN965_Pad_TopBottom
Y_GND1: MountingHole_Pad; MountingHole_2.2mm_M2_DIN965_Pad_TopBottom
Y_SIG1: MountingHole_Pad; MountingHole_2.2mm_M2_DIN965_Pad_TopBottom

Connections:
+3V3: C2.1, C6.1, C25.1, C26.1, IC3.11 (VREFB), IC3.13 (VREFA), IC4.11 (VREFB), IC4.13 (VREFA), IC5.11 (VREFB), IC5.13 (VREFA), L1.2, R4.1, R6.1, R25.2, R26.2, R27.2, RV1.3, RV2.3
+12V: C1.1, C9.1, C11.1, C13.1, C21.1, C23.1, IC1.4 (V+), IC2.6 (+VOUT), IC6.4 (V+), J7.1, U3.3 (VI)
-3V3: IC1.14 (OUT), R31.1, RV1.1, RV2.1
-12V: C10.2, C12.2, C14.2, C22.1, C24.1, IC1.11 (V-), IC2.4 (-VOUT), IC6.11 (V-), J7.3
/CS1: J3.14, U1.38 (16_A2_RX4_SCL1)
/MOSI: IC3.5 (SDI), IC4.5 (SDI), J1.13, U1.13 (11_MOSI_CTX1)
/MOSI1: IC5.5 (SDI), J1.18, U1.18 (26_A12_MOSI1)
/Pwr_In: C3.1, C4.1, C19.1, IC2.1 (+VIN), J6.1, U5.1 (VI)
/SCK: IC3.4 (SCK), IC4.4 (SCK), J3.11, U1.35 (13_SCK_LED)
/SCK1: IC5.4 (SCK), J1.19, U1.19 (27_A13_SCK1)
AGND: BL_GND1.1, C1.2, C2.2, C5.2, C6.2, C7.2, C8.2, C9.2, C10.1, C11.2, C12.1, C13.2, C14.1, C15.2, C16.2, C17.2, C18.2, C21.2, C22.2, C23.2, C24.2, C25.2, C26.2, C27.2, GR_GND1.1, IC1.12 (+IN), IC2.5 (COM), IC3.8 (~LDAC), IC3.12 (VSS), IC4.8 (~LDAC), IC4.12 (VSS), IC5.8 (~LDAC), IC5.12 (VSS), J3.10, J7.2, R3.1, R5.1, R9.1, R10.1, R14.1, R28.2, R29.2, R30.2, RE_GND1.1, TP1.1, TP2.1, U1.34 (GND), U3.2 (GND), X_GND1.1, Y_GND1.1
GND: C3.2, C4.2, C19.2, C20.2, IC2.2 (-VIN), J1.1, J2.3, J6.2, SW1.2, SW2.1, SW3.2, SW4.2, SW5.1, U1.1 (GND), U1.52 (GND), U5.2 (GND)
unnamed: BL_SIG1.1, R21.2
unnamed: C5.1, C7.1, C8.1, C15.1, C16.1, C17.1, C18.1, C27.1, IC3.1 (VDD), IC3.9 (~SHDN), IC4.1 (VDD), IC4.9 (~SHDN), IC5.1 (VDD), IC5.9 (~SHDN), L1.1, TP3.1, U3.1 (VO)
unnamed: C20.1, J3.24, U1.48 (VIN), U5.3 (VO)
unnamed: GR_SIG1.1, R20.2
unnamed: IC1.1 (OUT), R12.1, R20.1
unnamed: IC1.2 (-IN), R12.2, R28.1
unnamed: IC1.3 (+IN), R22.1
unnamed: IC1.5 (+IN), R24.1
unnamed: IC1.6 (-IN), R15.2, R30.1
unnamed: IC1.7 (OUT), R15.1, R21.1
unnamed: IC1.8 (OUT), R16.1, R19.1
unnamed: IC1.9 (-IN), R16.2, R29.1
unnamed: IC1.10 (+IN), R23.1
unnamed: IC1.13 (-IN), R27.1, R31.2
unnamed: IC3.3 (~CS), J3.20, U1.44 (22_A8_CTX1)
unnamed: IC3.10 (VOUTB), R14.2, R24.2
unnamed: IC3.14 (VOUTA), J8.1
unnamed: IC4.3 (~CS), IC5.3 (~CS), J1.8, U1.8 (6_OUT1D)
unnamed: IC4.10 (VOUTB), R9.2, R22.2
unnamed: IC4.14 (VOUTA), R2.1
unnamed: IC5.10 (VOUTB), R10.2, R23.2
unnamed: IC5.14 (VOUTA), R1.1
unnamed: IC6.1 (OUT), R18.1, RV4.1
unnamed: IC6.2 (-IN), R13.2, RV4.2
unnamed: IC6.3 (+IN), RV2.2
unnamed: IC6.5 (+IN), R2.2, R5.2, R26.1
unnamed: IC6.6 (-IN), R6.2, R8.1
unnamed: IC6.7 (OUT), R8.2, R13.1
unnamed: IC6.8 (OUT), R7.2, R11.1
unnamed: IC6.9 (-IN), R4.2, R7.1
unnamed: IC6.10 (+IN), R1.2, R3.2, R25.1
unnamed: IC6.12 (+IN), RV1.2
unnamed: IC6.13 (-IN), R11.2, RV3.2
unnamed: IC6.14 (OUT), R17.1, RV3.1
unnamed: J1.2, SW2.2, U1.2 (0_RX1_CRX2_CS1)
unnamed: J1.3, SW4.1, U1.3 (1_TX1_CTX2_MISO1)
unnamed: J1.4, SW3.1, U1.4 (2_OUT2)
unnamed: J1.5, SW1.1, U1.5 (3_LRCLK2)
unnamed: J1.6, SW5.2, U1.6 (4_BCLK2)
unnamed: J1.7, U1.7 (5_IN2)
unnamed: J1.9, U1.9 (7_RX2_OUT1A)
unnamed: J1.10, U1.10 (8_TX2_IN1)
unnamed: J1.11, U1.11 (9_OUT1C)
unnamed: J1.12, U1.12 (10_CS_MQSR)
unnamed: J1.14, U1.14 (12_MISO_MQSL)
unnamed: J1.15, U1.15 (3V3)
unnamed: J1.16, U1.16 (24_A10_TX6_SCL2)
unnamed: J1.17, U1.17 (25_A11_RX6_SDA2)
unnamed: J1.20, U1.20 (28_RX7)
unnamed: J1.21, U1.21 (29_TX7)
unnamed: J1.22, U1.22 (30_CRX3)
unnamed: J1.23, U1.23 (31_CTX3)
unnamed: J1.24, U1.24 (32_OUT1B)
unnamed: J2.1, U1.50 (VBAT)
unnamed: J2.2, U1.51 (3V3)
unnamed: J2.4, U1.53 (PROGRAM)
unnamed: J2.5, U1.54 (ON_OFF)
unnamed: J3.1, U1.25 (33_MCLK2)
unnamed: J3.2, U1.26 (34_RX8)
unnamed: J3.3, U1.27 (35_TX8)
unnamed: J3.4, U1.28 (36_CS)
unnamed: J3.5, U1.29 (37_CS)
unnamed: J3.6, U1.30 (38_CS1_IN1)
unnamed: J3.7, U1.31 (39_MISO1_OUT1A)
unnamed: J3.8, U1.32 (40_A16)
unnamed: J3.9, U1.33 (41_A17)
unnamed: J3.12, U1.36 (14_A0_TX3_SPDIF_OUT)
unnamed: J3.13, U1.37 (15_A1_RX3_SPDIF_IN)
unnamed: J3.15, U1.39 (17_A3_TX4_SDA1)
unnamed: J3.16, U1.40 (18_A4_SDA)
unnamed: J3.17, U1.41 (19_A5_SCL)
unnamed: J3.18, U1.42 (20_A6_TX5_LRCLK1)
unnamed: J3.19, U1.43 (21_A7_RX5_BCLK1)
unnamed: J3.21, U1.45 (23_A9_CRX1_MCLK1)
unnamed: J3.22, U1.46 (3V3)
unnamed: J3.23, U1.47 (GND)
unnamed: J3.25, U1.49 (VUSB)
unnamed: J9.1, U1.66 (D-)
unnamed: J9.2, U1.67 (D+)
unnamed: R17.2, X_SIG1.1
unnamed: R18.2, Y_SIG1.1
unnamed: R19.2, RE_SIG1.1

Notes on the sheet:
Red output from DAC
Using a digital ground for the return for the digital SPI signals
Horizontal size adjustment
Vertical size adjustment
XY outputs
within 4mm of VDD pin
X output from DAC
Red
Green
Vertical centering
Blue output from DAC
Control buttons
The + of the opamps is pulled to the middle so that when powered on and the DACS are in a high impedance state, the output will be the center. This forces the gain of this first stage to be 2 so the first stage will have about +/- 3 V range because of the initial divider
Power supply section
The second stage has a nominal gain of 2 to give +/- 6V output which is correct for the Y input The gain pot can be turned up to give +/- 8 for X
Blue
Spare output from DAC
R15,16,12 changed to 15K and the software changed to use half scale on the DACs to speed up RGB intensity changes
Digital to analogue conversion
Place close to opamps
Split VIN/VUSB pad on Teensy if external supply used
Optional 5V, 9V or 12V input from external supply
Use: RB-0512D (5V) RB-0912D (9V) RB-1212D (12V)
Horizontal centering
Green output from DAC
XY amplifiers
On original boards white colors would have distortion because of drops in the power line. Add decoupling caps on the left to opamps to prevent this
Add these 3 parts if optional 9V or 12V external supply is used (5V external doesn't work with LM2940)
Optional 12V input from external supply
Capacitors must be < 5mm from voltage regulators
Y output from DAC
RGB outputs
RGB amplifiers

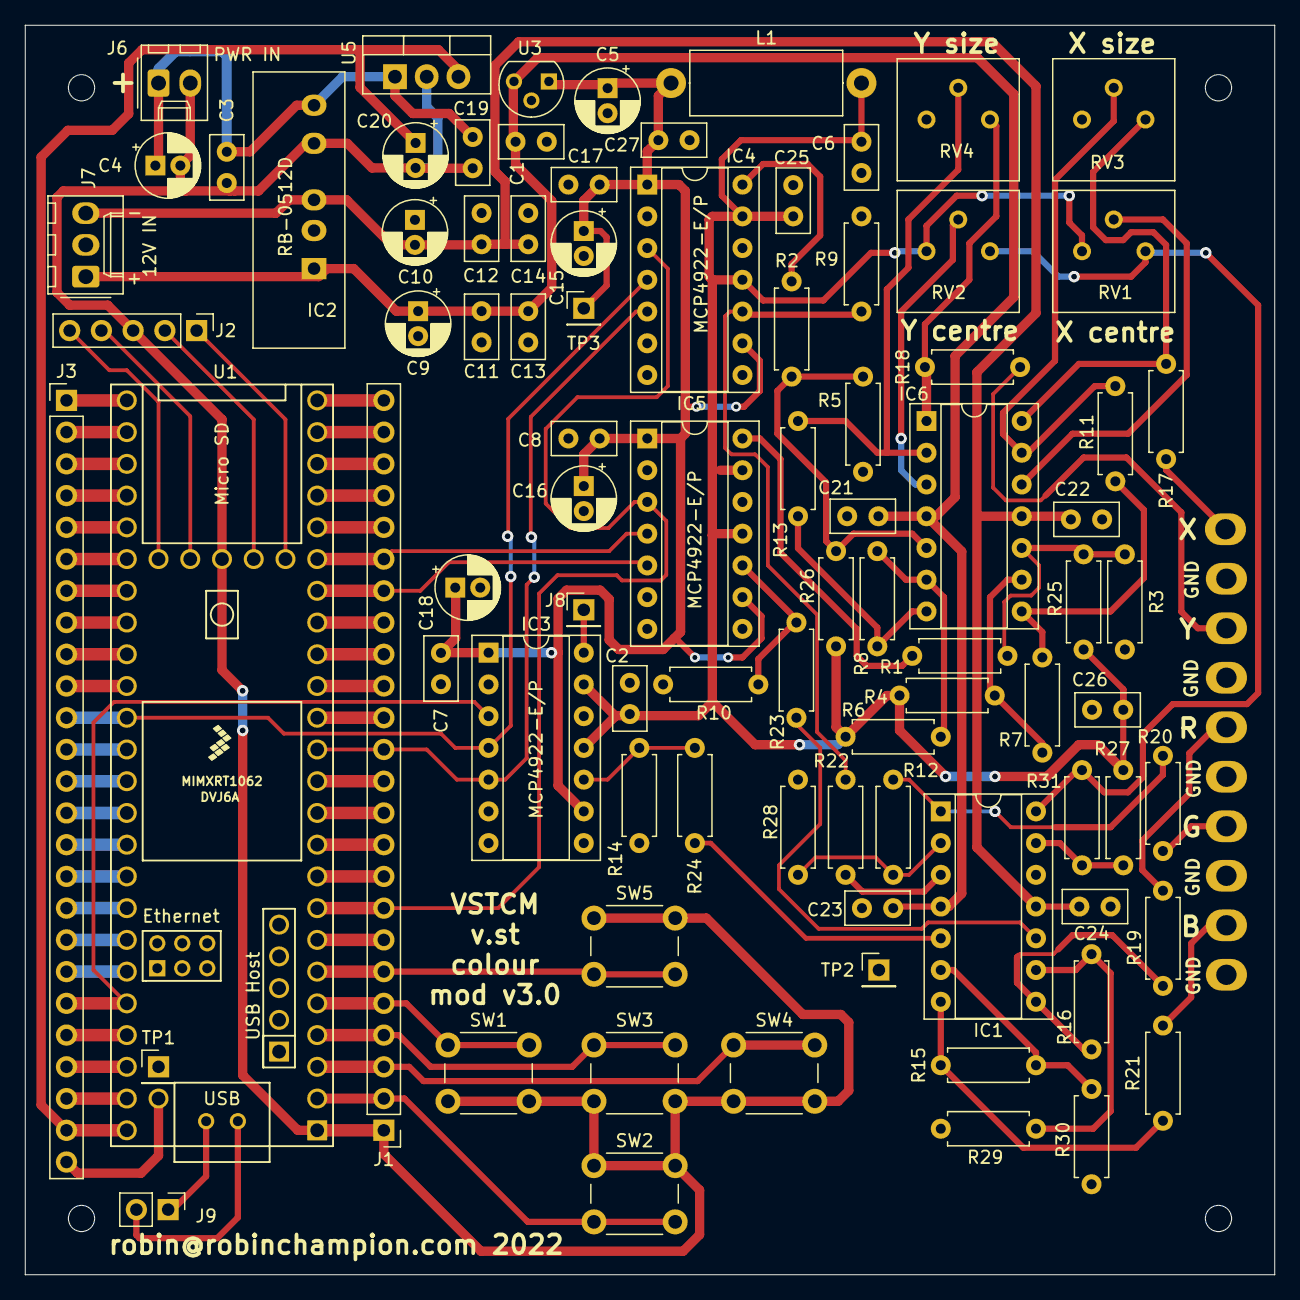
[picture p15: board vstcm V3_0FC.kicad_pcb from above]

Board: 2 copper layers, 100.0 x 100.0 mm, 101 parts (0 on the bottom side), 94 nets.

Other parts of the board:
REF01, REF02, REF03, REF04: MountingHole_2.1mm

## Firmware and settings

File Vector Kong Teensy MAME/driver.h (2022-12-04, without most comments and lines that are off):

#define DRIVER_H
#define LSB_FIRST 1
#define INLINE static
#include "common.h"
#include "palette.h"
#include "mame.h"
#include "cpuintrf.h"
#include "memory.h"
#include "sndhrdw/generic.h"
#include "inptport.h"
struct InputPort
{
	unsigned char mask;
	unsigned char default_value;
	int type;
	const char *name;
	int keyboard;
	int joystick;
	int arg;
};
#define IP_ACTIVE_HIGH 0x00
#define IP_ACTIVE_LOW 0xff
enum { IPT_END=1,IPT_PORT,
	IPT_JOYSTICK_UP, IPT_JOYSTICK_DOWN, IPT_JOYSTICK_LEFT, IPT_JOYSTICK_RIGHT,
	IPT_JOYSTICKRIGHT_UP, IPT_JOYSTICKRIGHT_DOWN, IPT_JOYSTICKRIGHT_LEFT, IPT_JOYSTICKRIGHT_RIGHT,
	IPT_JOYSTICKLEFT_UP, IPT_JOYSTICKLEFT_DOWN, IPT_JOYSTICKLEFT_LEFT, IPT_JOYSTICKLEFT_RIGHT,
	IPT_BUTTON1, IPT_BUTTON2, IPT_BUTTON3, IPT_BUTTON4,
	IPT_BUTTON5, IPT_BUTTON6, IPT_BUTTON7, IPT_BUTTON8,
	IPT_ANALOG_START,
	IPT_PADDLE, IPT_DIAL, IPT_TRACKBALL_X, IPT_TRACKBALL_Y, IPT_AD_STICK_X, IPT_AD_STICK_Y,
	IPT_ANALOG_END,
	IPT_COIN1, IPT_COIN2, IPT_COIN3, IPT_COIN4,
	IPT_START1, IPT_START2, IPT_START3, IPT_START4,
	IPT_SERVICE, IPT_TILT,
	IPT_DIPSWITCH_NAME, IPT_DIPSWITCH_SETTING,
	IPT_VBLANK,
	IPT_UNKNOWN
};
#define IPT_UNUSED     IPF_UNUSED
#define IPF_MASK       0xffff0000
#define IPF_UNUSED     0x80000000
#define IPF_COCKTAIL   IPF_PLAYER2
#define IPF_CHEAT      0x40000000
#define IPF_PLAYERMASK 0x00030000
#define IPF_PLAYER1    0
#define IPF_PLAYER2    0x00010000
#define IPF_PLAYER3    0x00020000
#define IPF_PLAYER4    0x00030000
#define IPF_8WAY       0
#define IPF_4WAY       0x00080000
#define IPF_2WAY       0
#define IPF_IMPULSE    0x00100000
#define IPF_TOGGLE     0x00200000
#define IPF_REVERSE    0x00400000
#define IPF_CENTER     0x00800000
#define IPF_CUSTOM_UPDATE 0x01000000
#define IPF_RESETCPU   0x02000000
#define IPF_SENSITIVITY(percent)	(percent&0xff)
#define IPF_CLIP(clip)			((clip&0xff) << 8  )
#define IPF_MIN(min)			((min&0xff)  << 16 )
#define IPF_MAX(max)			((max&0xff)  << 24 )
#define IPF_DEC(key)			((key&0xff)       )
#define IPF_INC(key)			((key&0xff) << 8  )
#define IPF_DELTA(val)			((val&0xff) << 16 )
#define IP_NAME_DEFAULT ((const char *)-1)
#define IP_KEY_DEFAULT -1
#define IP_KEY_NONE -2
#define IP_KEY_PREVIOUS -3
#define IP_JOY_DEFAULT -1
#define IP_JOY_NONE -2
#define IP_JOY_PREVIOUS -3
#define INPUT_PORTS_START(name) static struct InputPort name[] = {
#define INPUT_PORTS_END { 0, 0, IPT_END, 0, 0 } };
#define PORT_START { 0, 0, IPT_PORT, 0, 0, 0, 0 },
#define PORT_BIT(mask,default,type) { mask, default, type, IP_NAME_DEFAULT, IP_KEY_DEFAULT, IP_JOY_DEFAULT, 0 },
#define PORT_BITX(mask,default,type,name,key,joy,arg) { mask, default, type, name, key, joy, arg },
#define PORT_ANALOG(mask,default,type,sensitivity,clip,min,max) \
	{ mask, default, type, IP_NAME_DEFAULT, \
	IP_KEY_DEFAULT, IP_JOY_DEFAULT, \
	IPF_SENSITIVITY(sensitivity) | IPF_CLIP(clip) | IPF_MIN(min) | IPF_MAX(max) },
#define PORT_ANALOGX(mask,default,type,sensitivity,clip,min,max,keydec,keyinc,joydec,joyinc,delta) \
	{ mask, default, type, IP_NAME_DEFAULT, \
	IPF_DEC(keydec) | IPF_INC(keyinc) | IPF_DELTA(delta), IPF_DEC(joydec) | IPF_INC(joyinc) | IPF_DELTA(delta), \
	IPF_SENSITIVITY(sensitivity) | IPF_CLIP(clip) | IPF_MIN(min) | IPF_MAX(max) },
#define PORT_DIPNAME(mask,default,name,key) { mask, default, IPT_DIPSWITCH_NAME, name, key, IP_JOY_NONE, 0 },
#define PORT_DIPSETTING(default,name) { 0, default, IPT_DIPSWITCH_SETTING, name, IP_KEY_NONE, IP_JOY_NONE, 0 },
struct MachineCPU
{
	int cpu_type;
	int cpu_clock;
	int memory_region;
	const struct MemoryReadAddress *memory_read;
	const struct MemoryWriteAddress *memory_write;
	const struct IOReadPort *port_read;
	const struct IOWritePort *port_write;
	int (*vblank_interrupt)(void);
	int vblank_interrupts_per_frame;
	int (*timed_interrupt)(void);
	int timed_interrupts_per_second;
};
#define CPU_Z80       1
#define CPU_8085A     2
#define CPU_8080     CPU_8085A
#define CPU_M6502     3
#define CPU_I86       4
#define CPU_I8039     5
#define CPU_I8035    CPU_I8039
#define CPU_M6803     6
#define CPU_M6802    CPU_M6803
#define CPU_M6808    CPU_M6803
#define CPU_HD63701  CPU_M6803
#define CPU_M6805     7
#define CPU_M68705   CPU_M6805
#define CPU_M6809     8
#define CPU_M6309    CPU_M6809
#define CPU_M68000    9
#define CPU_T11      10
#define CPU_S2650    11
#define CPU_TMS34010 12
#define CPU_TMS9900  13
#define CPU_AUDIO_CPU 0x8000
#define CPU_16BIT_PORT 0x4000
#define CPU_FLAGS_MASK 0xff00
#define MAX_CPU 4
struct MachineSound
{
	int sound_type;
	void *sound_interface;
};
#define SOUND_CUSTOM     1
#define SOUND_SAMPLES    2
#define SOUND_DAC        3
#define SOUND_AY8910     4
#define SOUND_YM2203     5
#define SOUND_YM2151     6
#define SOUND_YM2151_ALT 7
#define SOUND_YM2413     8
#define SOUND_YM2610     9
#define SOUND_YM3812    10
#define SOUND_YM3526    11	//SOUND_YM3812	/* 100% compatible, less features */
#define SOUND_SN76496   12
#define SOUND_POKEY     13
#define SOUND_NES       14
#define SOUND_ASTROCADE 15
#define SOUND_NAMCO     16
#define SOUND_TMS5220   17
#define SOUND_VLM5030   18
#define SOUND_ADPCM     19
#define SOUND_OKIM6295  20
#define SOUND_MSM5205   21
#define SOUND_HC55516   22
#define MAX_SOUND 4
struct MachineDriver
{
	struct MachineCPU cpu[MAX_CPU];
	int frames_per_second;
	int vblank_duration;
	int cpu_slices_per_frame;
	void (*init_machine)(void);
	int screen_width,screen_height;
	struct rectangle visible_area;
	struct GfxDecodeInfo *gfxdecodeinfo;
	unsigned int total_colors;
	unsigned int color_table_len;
	void (*vh_convert_color_prom)(unsigned char *palette, unsigned short *colortable,const unsigned char *color_prom);
	int video_attributes;
	int unused;
	int (*vh_start)(void);
	void (*vh_stop)(void);
	void (*vh_update)(struct osd_bitmap *bitmap,int full_refresh);
	int sound_attributes;
	int (*sh_start)(void);
	void (*sh_stop)(void);
	void (*sh_update)(void);
	struct MachineSound sound[MAX_SOUND];
};
#define DEFAULT_60HZ_VBLANK_DURATION 0
#define DEFAULT_30HZ_VBLANK_DURATION 0
#define DEFAULT_REAL_60HZ_VBLANK_DURATION 2500
#define DEFAULT_REAL_30HZ_VBLANK_DURATION 2500
#define	VIDEO_TYPE_RASTER			0x0000
#define	VIDEO_TYPE_VECTOR			0x0001
#define	VIDEO_SUPPORTS_DIRTY		0x0002
#define	VIDEO_MODIFIES_PALETTE	0x0004
#define	VIDEO_SUPPORTS_16BIT		0x0008
#define	VIDEO_UPDATE_BEFORE_VBLANK	0x0010
#define VIDEO_PIXEL_ASPECT_RATIO_MASK 0x0060
#define VIDEO_PIXEL_ASPECT_RATIO_1_1 0x0000
#define VIDEO_PIXEL_ASPECT_RATIO_1_2 0x0020
#define VIDEO_PIXEL_ASPECT_RATIO_3_2 0x0040
#define	SOUND_SUPPORTS_STEREO		0x0001
struct GameDriver
{
	const char *source_file;
	const struct GameDriver *clone_of;
	const char *name;
	const char *description;
	const char *year;
	const char *manufacturer;
	const char *credits;
	int flags;
	const struct MachineDriver *drv;
	void (*driver_init)(void);
	const struct RomModule *rom;
	void (*rom_decode)(void);
	void (*opcode_decode)(void);
	const char **samplenames;
	const unsigned char *sound_prom;
	struct InputPort *input_ports;
	const unsigned char *color_prom;
	const unsigned char *palette;
	const unsigned short *colortable;
	int orientation;
	int (*hiscore_load)(void);
	void (*hiscore_save)(void);
};
#define GAME_NOT_WORKING		0x0001
#define GAME_WRONG_COLORS		0x0002
#define GAME_IMPERFECT_COLORS	0x0004
#define PROM_MEMORY_REGION(region) ((const unsigned char *)((-(region))-1))
#define	ORIENTATION_DEFAULT		0x00
#define	ORIENTATION_FLIP_X		0x01
#define	ORIENTATION_FLIP_Y		0x02
#define ORIENTATION_SWAP_XY		0x04
#define	ORIENTATION_ROTATE_90	(ORIENTATION_SWAP_XY|ORIENTATION_FLIP_X)
#define	ORIENTATION_ROTATE_180	(ORIENTATION_FLIP_X|ORIENTATION_FLIP_Y)
#define	ORIENTATION_ROTATE_270	(ORIENTATION_SWAP_XY|ORIENTATION_FLIP_Y)
extern const struct GameDriver *drivers[];

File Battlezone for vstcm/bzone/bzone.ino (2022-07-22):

/*
   Atari Vector game simulator / Battlezone

   Copyright 1991, 1993, 1996 Hedley Rainnie, Doug Neubauer, and Eric Smith
   Copyright 2015 Hedley Rainnie

   6502 simulator by Hedley Rainnie, Doug Neubauer, and Eric Smith

   Adapted for vstcm by Robin Champion June 2022
   https://github.com/english1234/vstcm

   Controls work using IR remote on vstcm

   Sound is experimental!
   
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
*/

#include <stdio.h>
#include <SD.h>
#include <IRremote.hpp>
#include <sys/types.h>
#include <Audio.h>
#include <Wire.h>
#include <SPI.h>
#include <SD.h>
#include <SerialFlash.h>
#include "bzone.h"

void dopush(uint8_t val, uint16_t PC)
{
  uint16_t addr;
  addr = g_cpu_SP + 0x100;
  g_cpu_SP--;
  g_cpu_SP &= 0xff;
  memwr (addr, val, PC, 0);
}

uint8_t dopop(uint16_t PC)
{
  uint16_t addr;
  g_cpu_SP++;
  g_cpu_SP &= 0xff;
  addr = g_cpu_SP + 0x100;
  return (memrd(addr, PC, 0));
}

void loop()
{
  int32_t PC;
  int32_t opcode;
  int32_t addr;
  int32_t A;
  int32_t X;
  int32_t Y;
  DECLARE_CC;
  uint32_t totcycles;

  A = g_cpu_save_A;
  X = g_cpu_save_X;
  Y = g_cpu_save_Y;
  byte_to_flags (g_cpu_save_flags);
  PC = g_cpu_save_PC;
  totcycles = g_cpu_save_totcycles;

test_interrupt:

#ifdef WRAP_CYC_COUNT   // I've commented out this definition for the moment just to see what happens (RC)
  if (totcycles > WRAP_CYC_COUNT)
  {
    if (g_cpu_irq_cycle >= (totcycles - WRAP_CYC_COUNT))
      g_cpu_irq_cycle -= WRAP_CYC_COUNT;

    if (g_vctr_vg_done_cyc >= (totcycles - WRAP_CYC_COUNT))
      g_vctr_vg_done_cyc -= WRAP_CYC_COUNT;

    totcycles -= WRAP_CYC_COUNT;
    g_cpu_cyc_wraps++;
  }
#endif

  if (totcycles > g_cpu_irq_cycle)
  {
    if (!g_sys_self_test)
    {
      /* do NMI */
      dopush(PC >> 8, PC);
      dopush(PC & 0xff, PC);
      dopush(flags_to_byte, PC);
      SET_I;
      PC = memrdwd(0xfffa, PC, totcycles);
      totcycles += 7;
      //          g_cpu_irq_cycle += 6144; // <<<<<< hkjr 03/30/14. NMI in an MMI occasionally with a # like this...
      g_cpu_irq_cycle += g_cpu_irq_cycle_off;
    }
  }

  while (1) {
#if 0
    pc_ring[ring_idx++] = PC;
    ring_idx &= 0x3f;
#endif
#ifdef TRACEFIFO
    fifo[pcpos].PC = PC;
    fifo[pcpos].A = A;
    fifo[pcpos].X = X;
    fifo[pcpos].Y = Y;
    fifo[pcpos].flags = flags_to_byte;
    fifo[pcpos].SP = g_cpu_SP;
    pcpos = (pcpos + 1) & 0x1fff;
#endif
    if (PC == 0x7985)
      start_sample(A);       // pokey audio
    else if (PC == 0x6a22)
      enable_sound(SMART);    // smart missile (pokey ch3&4)

    opcode = g_sys_mem[PC++].cell;

    switch (opcode)
    { // execute opcode
      case 0x69:  /* ADC */  EA_IMM    DO_ADC   C( 2)  break;
      case 0x6d:  /* ADC */  EA_ABS    DO_ADC   C( 3)  break;
      case 0x65:  /* ADC */  EA_ZP     DO_ADC   C( 4)  break;
      case 0x61:  /* ADC */  EA_IND_X  DO_ADC   C( 6)  break;
      case 0x71:  /* ADC */  EA_IND_Y  DO_ADC   C( 5)  break;
      case 0x75:  /* ADC */  EA_ZP_X   DO_ADC   C( 4)  break;
      case 0x7d:  /* ADC */  EA_ABS_X  DO_ADC   C( 4)  break;
      case 0x79:  /* ADC */  EA_ABS_Y  DO_ADC   C( 4)  break;

      case 0x29:  /* AND */  EA_IMM    DO_AND   C( 2)  break;
      case 0x2d:  /* AND */  EA_ABS    DO_AND   C( 4)  break;
      case 0x25:  /* AND */  EA_ZP     DO_AND   C( 3)  break;
      case 0x21:  /* AND */  EA_IND_X  DO_AND   C( 6)  break;
      case 0x31:  /* AND */  EA_IND_Y  DO_AND   C( 5)  break;
      case 0x35:  /* AND */  EA_ZP_X   DO_AND   C( 4)  break;
      case 0x39:  /* AND */  EA_ABS_Y  DO_AND   C( 4)  break;
      case 0x3d:  /* AND */  EA_ABS_X  DO_AND   C( 4)  break;

      case 0x0e:  /* ASL */  EA_ABS    DO_ASL   C( 6)  break;
      case 0x06:  /* ASL */  EA_ZP     DO_ASL   C( 5)  break;
      case 0x0a:  /* ASL */            DO_ASLA  C( 2)  break;
      case 0x16:  /* ASL */  EA_ZP_X   DO_ASL   C( 6)  break;
      case 0x1e:  /* ASL */  EA_ABS_X  DO_ASL   C( 7)  break;

      case 0x90:  /* BCC */		 DO_BCC   C( 2)  goto test_interrupt;
      case 0xb0:  /* BCS */		 DO_BCS   C( 2)  goto test_interrupt;
      case 0xf0:  /* BEQ */		 DO_BEQ   C( 2)  goto test_interrupt;
      case 0x30:  /* BMI */		 DO_BMI   C( 2)  goto test_interrupt;
      case 0xd0:  /* BNE */		 DO_BNE   C( 2)  goto test_interrupt;
      case 0x10:  /* BPL */		 DO_BPL   C( 2)  goto test_interrupt;
      case 0x50:  /* BVC */		 DO_BVC   C( 2)  goto test_interrupt;
      case 0x70:  /* BVS */		 DO_BVS   C( 2)  goto test_interrupt;

      case 0x2c:  /* BIT */  EA_ABS    DO_BIT   C( 4)  break;
      case 0x24:  /* BIT */  EA_ZP     DO_BIT   C( 3)  break;

#if 1
      case 0x00:  /* BRK */            DO_BRK   C( 7)  break;
#endif

      case 0x18:  /* CLC */            DO_CLC   C( 2)  break;
      case 0xd8:  /* CLD */            DO_CLD   C( 2)  break;
      case 0x58:  /* CLI */            DO_CLI   C( 2)  goto test_interrupt;
      case 0xb8:  /* CLV */            DO_CLV   C( 2)  break;

      case 0xc9:  /* CMP */  EA_IMM    DO_CMP   C( 2)  break;
      case 0xcd:  /* CMP */  EA_ABS    DO_CMP   C( 4)  break;
      case 0xc5:  /* CMP */  EA_ZP     DO_CMP   C( 3)  break;
      case 0xc1:  /* CMP */  EA_IND_X  DO_CMP   C( 6)  break;
      case 0xd1:  /* CMP */  EA_IND_Y  DO_CMP   C( 5)  break;
      case 0xd5:  /* CMP */  EA_ZP_X   DO_CMP   C( 4)  break;
      case 0xd9:  /* CMP */  EA_ABS_Y  DO_CMP   C( 4)  break;
      case 0xdd:  /* CMP */  EA_ABS_X  DO_CMP   C( 4)  break;

      case 0xe0:  /* CPX */  EA_IMM    DO_CPX   C( 2)  break;
      case 0xec:  /* CPX */  EA_ABS    DO_CPX   C( 4)  break;
      case 0xe4:  /* CPX */  EA_ZP     DO_CPX   C( 3)  break;

      case 0xc0:  /* CPY */  EA_IMM    DO_CPY   C( 2)  break;
      case 0xcc:  /* CPY */  EA_ABS    DO_CPY   C( 4)  break;
      case 0xc4:  /* CPY */  EA_ZP     DO_CPY   C( 3)  break;

      case 0xce:  /* DEC */  EA_ABS    DO_DEC   C( 6)  break;
      case 0xc6:  /* DEC */  EA_ZP     DO_DEC   C( 5)  break;
      case 0xd6:  /* DEC */  EA_ZP_X   DO_DEC   C( 6)  break;
      case 0xde:  /* DEC */  EA_ABS_X  DO_DEC   C( 7)  break;

      case 0xca:  /* DEX */            DO_DEX   C( 2)  break;
      case 0x88:  /* DEY */            DO_DEY   C( 2)  break;

      case 0x49:  /* EOR */  EA_IMM    DO_EOR   C( 2)  break;
      case 0x4d:  /* EOR */  EA_ABS    DO_EOR   C( 4)  break;
      case 0x45:  /* EOR */  EA_ZP     DO_EOR   C( 3)  break;
      case 0x41:  /* EOR */  EA_IND_X  DO_EOR   C( 6)  break;
      case 0x51:  /* EOR */  EA_IND_Y  DO_EOR   C( 5)  break;
      case 0x55:  /* EOR */  EA_ZP_X   DO_EOR   C( 4)  break;
      case 0x59:  /* EOR */  EA_ABS_Y  DO_EOR   C( 4)  break;
      case 0x5d:  /* EOR */  EA_ABS_X  DO_EOR   C( 4)  break;

      case 0xee:  /* INC */  EA_ABS    DO_INC   C( 6)  break;
      case 0xe6:  /* INC */  EA_ZP     DO_INC   C( 5)  break;
      case 0xf6:  /* INC */  EA_ZP_X   DO_INC   C( 6)  break;
      case 0xfe:  /* INC */  EA_ABS_X  DO_INC   C( 7)  break;

      case 0xe8:  /* INX */            DO_INX   C( 2)  break;
      case 0xc8:  /* INY */            DO_INY   C( 2)  break;

      case 0x4c:  /* JMP */  EA_ABS    DO_JMP   C( 3)  goto test_interrupt;
      case 0x6c:  /* JMP */  EA_IND    DO_JMP   C( 5)  goto test_interrupt;

      case 0x20:  /* JSR */  EA_ABS    DO_JSR   C( 6)  goto test_interrupt;

      case 0xa9:  /* LDA */  EA_IMM    DO_LDA   C( 2)  break;
      case 0xad:  /* LDA */  EA_ABS    DO_LDA   C( 4)  break;
      case 0xa5:  /* LDA */  EA_ZP     DO_LDA   C( 3)  break;
      case 0xa1:  /* LDA */  EA_IND_X  DO_LDA   C( 6)  break;
      case 0xb1:  /* LDA */  EA_IND_Y  DO_LDA   C( 5)  break;
      case 0xb5:  /* LDA */  EA_ZP_X   DO_LDA   C( 4)  break;
      case 0xb9:  /* LDA */  EA_ABS_Y  DO_LDA   C( 4)  break;
      case 0xbd:  /* LDA */  EA_ABS_X  DO_LDA   C( 4)  break;

      case 0xa2:  /* LDX */  EA_IMM    DO_LDX   C( 2)  break;
      case 0xae:  /* LDX */  EA_ABS    DO_LDX   C( 4)  break;
      case 0xa6:  /* LDX */  EA_ZP     DO_LDX   C( 3)  break;
      case 0xbe:  /* LDX */  EA_ABS_Y  DO_LDX   C( 4)  break;
      case 0xb6:  /* LDX */  EA_ZP_Y   DO_LDX   C( 4)  break;

      case 0xa0:  /* LDY */  EA_IMM    DO_LDY   C( 2)  break;
      case 0xac:  /* LDY */  EA_ABS    DO_LDY   C( 4)  break;
      case 0xa4:  /* LDY */  EA_ZP     DO_LDY   C( 3)  break;
      case 0xb4:  /* LDY */  EA_ZP_X   DO_LDY   C( 4)  break;
      case 0xbc:  /* LDY */  EA_ABS_X  DO_LDY   C( 4)  break;

      case 0x4e:  /* LSR */  EA_ABS    DO_LSR   C( 6)  break;
      case 0x46:  /* LSR */  EA_ZP     DO_LSR   C( 5)  break;
      case 0x4a:  /* LSR */            DO_LSRA  C( 2)  break;
      case 0x56:  /* LSR */  EA_ZP_X   DO_LSR   C( 6)  break;
      case 0x5e:  /* LSR */  EA_ABS_X  DO_LSR   C( 7)  break;

      case 0xea:  /* NOP */                     C( 2)  break;

      case 0x09:  /* ORA */  EA_IMM    DO_ORA   C( 2)  break;
      case 0x0d:  /* ORA */  EA_ABS    DO_ORA   C( 4)  break;
      case 0x05:  /* ORA */  EA_ZP     DO_ORA   C( 3)  break;
      case 0x01:  /* ORA */  EA_IND_X  DO_ORA   C( 6)  break;
      case 0x11:  /* ORA */  EA_IND_Y  DO_ORA   C( 5)  break;
      case 0x15:  /* ORA */  EA_ZP_X   DO_ORA   C( 4)  break;
      case 0x19:  /* ORA */  EA_ABS_Y  DO_ORA   C( 4)  break;
      case 0x1d:  /* ORA */  EA_ABS_X  DO_ORA   C( 4)  break;

      case 0x48:  /* PHA */            DO_PHA   C( 3)  break;
      case 0x08:  /* PHP */            DO_PHP   C( 3)  break;
      case 0x68:  /* PLA */            DO_PLA   C( 4)  break;
      case 0x28:  /* PLP */            DO_PLP   C( 4)  goto test_interrupt;

      case 0x2e:  /* ROL */  EA_ABS    DO_ROL   C( 6)  break;
      case 0x26:  /* ROL */  EA_ZP     DO_ROL   C( 5)  break;
      case 0x2a:  /* ROL */            DO_ROLA  C( 2)  break;
      case 0x36:  /* ROL */  EA_ZP_X   DO_ROL   C( 6)  break;
      case 0x3e:  /* ROL */  EA_ABS_X  DO_ROL   C( 7)  break;

      case 0x6e:  /* ROR */  EA_ABS    DO_ROR   C( 6)  break;
      case 0x66:  /* ROR */  EA_ZP     DO_ROR   C( 5)  break;
      case 0x6a:  /* ROR */            DO_RORA  C( 2)  break;
      case 0x76:  /* ROR */  EA_ZP_X   DO_ROR   C( 6)  break;
      case 0x7e:  /* ROR */  EA_ABS_X  DO_ROR   C( 7)  break;

      case 0x40:  /* RTI */            DO_RTI   C( 6)  goto test_interrupt;
      case 0x60:  /* RTS */            DO_RTS   C( 6)  goto test_interrupt;

      case 0xe9:  /* SBC */  EA_IMM    DO_SBC   C( 2)  break;
      case 0xed:  /* SBC */  EA_ABS    DO_SBC   C( 4)  break;
      case 0xe5:  /* SBC */  EA_ZP     DO_SBC   C( 3)  break;
      case 0xe1:  /* SBC */  EA_IND_X  DO_SBC   C( 6)  break;
      case 0xf1:  /* SBC */  EA_IND_Y  DO_SBC   C( 5)  break;
      case 0xf5:  /* SBC */  EA_ZP_X   DO_SBC   C( 4)  break;
      case 0xf9:  /* SBC */  EA_ABS_Y  DO_SBC   C( 4)  break;
      case 0xfd:  /* SBC */  EA_ABS_X  DO_SBC   C( 4)  break;

      case 0x38:  /* SEC */            DO_SEC   C( 2)  break;
      case 0xf8:  /* SED */            DO_SED   C( 2)  break;
      case 0x78:  /* SEI */            DO_SEI   C( 2)  break;

      case 0x8d:  /* STA */  EA_ABS    DO_STA   C( 4)  break;
      case 0x85:  /* STA */  EA_ZP     DO_STA   C( 3)  break;
      case 0x81:  /* STA */  EA_IND_X  DO_STA   C( 6)  break;
      case 0x91:  /* STA */  EA_IND_Y  DO_STA   C( 6)  break;
      case 0x95:  /* STA */  EA_ZP_X   DO_STA   C( 4)  break;
      case 0x99:  /* STA */  EA_ABS_Y  DO_STA   C( 5)  break;
      case 0x9d:  /* STA */  EA_ABS_X  DO_STA   C( 5)  break;

      case 0x8e:  /* STX */  EA_ABS    DO_STX   C( 4)  break;
      case 0x86:  /* STX */  EA_ZP     DO_STX   C( 3)  break;
      case 0x96:  /* STX */  EA_ZP_Y   DO_STX   C( 4)  break;

      case 0x8c:  /* STY */  EA_ABS    DO_STY   C( 4)  break;
      case 0x84:  /* STY */  EA_ZP     DO_STY   C( 3)  break;
      case 0x94:  /* STY */  EA_ZP_X   DO_STY   C( 4)  break;

      case 0xaa:  /* TAX */            DO_TAX   C( 2)  break;
      case 0xa8:  /* TAY */            DO_TAY   C( 2)  break;
      case 0x98:  /* TYA */            DO_TYA   C( 2)  break;
      case 0xba:  /* TSX */            DO_TSX   C( 2)  break;
      case 0x8a:  /* TXA */            DO_TXA   C( 2)  break;
      case 0x9a:  /* TXS */            DO_TXS   C( 2)  break;

      default:
        break;
    }
  }
}

// memory and I/O functions for Atari Vector game simulator

/*
   This used to decrement the switch variable if it was non-zero, so that
   they would automatically release.  This has been changed to increment
   it if less than zero, so switches set by the debugger will release, but
   to leave it alone if it is greater than zero, for keyboard handling.
*/
int32_t check_switch_decr(int32_t *sw)
{
  if ((*sw) < 0)
  {
    (*sw)++;
    if ((*sw) == 0)
      ;
  }

  return ((*sw) != 0);
}

uint8_t MEMRD(uint32_t addr, int32_t PC, uint32_t cyc)
{
  uint8_t tag;
  uint8_t result = 0;

  if (!(tag = g_sys_mem[addr].tagr))
    return (g_sys_mem[addr].cell);

  switch (tag & 0x3f)
  {
    case MEMORY:
      result = g_sys_mem[addr].cell;
      break;
    case MEMORY1:
      result = g_sys_sram[addr & 0x3ff];
      break;
    case MEMORY_BB:
      break;
    case VECRAM:
      result = g_sys_vram[addr & 0xfff];
      break;
    case COININ:
      result =
        ((! check_switch_decr(&g_sys_cslot_right))) |
        ((! check_switch_decr(&g_sys_cslot_left)) << 1) |
        ((! check_switch_decr(&g_sys_cslot_util)) << 2) |
        ((! check_switch_decr(&g_sys_slam)) << 3) |
        ((! g_sys_self_test) << 4) |
        (1 << 5) | // signature analysis
        (vg_done(cyc) << 6) |
        // clock toggles at 3 KHz
        ((cyc >> 1) & 0x80);

      break;
    case EAROMRD:
      result = 0;
      break;
    case OPTSW1:
      result = g_sys_optionreg[0];
      break;
    case OPTSW2:
      result = g_sys_optionreg[1];
      break;
    case OPT1_2BIT:
      result = 0xfc | ((g_sys_optionreg[0] >> (2 * (3 - (addr & 0x3)))) & 0x3);
      break;
    case ASTEROIDS_SW1:
      break;
    case ASTEROIDS_SW2:
      break;
    case POKEY1:
      result = pokey_read(0, addr & 0x0f, PC, cyc);
      break;
    case POKEY2:
      result = pokey_read (1, addr & 0x0f, PC, cyc);
      break;
    case POKEY3:
      result = pokey_read (2, addr & 0x0f, PC, cyc);
      break;
    case POKEY4:
      result = pokey_read (3, addr & 0x0f, PC, cyc);
      break;
    case BZ_SOUND:
      break;
    case BZ_INPUTS:
      result = g_soc_curr_switch = read_gpio();
      break;
    case MBLO:
      result = mb_result & 0xff;
      break;
    case MBHI:
      result = (mb_result >> 8) & 0xff;
      break;
    case MBSTAT:
      result = 0x00;  /* always done! */
      break;
    case UNKNOWN:
      result = 0xff;
      break;
    default:
      result = 0xff;
      break;
  }

  if (tag & BREAKTAG)
    ;

  return result;
}

void MEMWR(uint32_t addr, int32_t val, int32_t PC, uint32_t cyc)
{
  uint8_t tag;
  int32_t newbank;

  if (!(tag = g_sys_mem[addr].tagw))
    g_sys_mem[addr].cell = val;
  else
  {
    switch (tag & 0x3f)
    {
      case MEMORY:
        g_sys_mem[addr].cell = val;
        break;
      case MEMORY1:
        g_sys_sram[addr & 0x3ff] = val;
        break;
      case MEMORY_BB:
        break;
      case VECRAM:
        g_sys_vram[addr & 0xfff] = val;
        break;
      case COINOUT:
        newbank = (val >> 2) & 1;
        g_sys_bank = newbank;
        break;
      case INTACK:
        g_cpu_irq_cycle = cyc + 6144;
        break;
      case WDCLR:
      case EAROMCON:
      case EAROMWR:
        /* none of these are implemented yet, but they're OK. */
        break;
      case VGRST:
        vg_reset(cyc);
        break;
      case VGO:
        g_vctr_vg_count++;
        // while (0 == g_soc_sixty_hz);    //requires IRQ to work
        g_soc_sixty_hz = 0;
        vg_go(cyc);
        break;
      case DMACNT:
        break;
      case COLORRAM:
        break;
      case TEMP_OUTPUTS:
        break;
      case ASTEROIDS_OUT:
        break;
      case ASTEROIDS_EXP:
        break;
      case ASTEROIDS_THUMP:
        break;
      case ASTEROIDS_SND:
        break;
      case ASTEROIDS_SND_RST:
        break;
      case POKEY1:
        pokey_write(0, addr & 0x0f, val, PC, cyc);
        break;
      case POKEY2:
        pokey_write(1, addr & 0x0f, val, PC, cyc);
        break;
      case POKEY3:
        pokey_write(2, addr & 0x0f, val, PC, cyc);
        break;
      case POKEY4:
        pokey_write(3, addr & 0x0f, val, PC, cyc);
        break;
      case BZ_SOUND:
        /*
          BZ_SOUNDS[7]  motoren
          BZ_SOUNDS[6]  start led
          BZ_SOUNDS[5]  sound en
          BZ_SOUNDS[4]  engine H/L
          BZ_SOUNDS[3]  shell L/S
          BZ_SOUNDS[2]  shell enabl
          BZ_SOUNDS[1]  explo L/S
          BZ_SOUNDS[0]  explo en
        */
        if (val & bit(5))
          g_aud_enable = 1;
        else
          g_aud_enable = 0;

        if (val & bit(0)) // expl
        {
          //    enable_sound((val & bit(1)) ? EXPLODE_HI : EXPLODE_LO);
          playSdRaw1.play("roms/Battlezone/explo.hex");
       /*   if (val & bit(1))
            playSdWav1.play("roms/Battlezone/explode1.wav");
          else
            playSdWav1.play("roms/Battlezone/explode2.wav");*/
        }
        if (val & bit(2))  // shell
        {
          //  enable_sound((val & bit(3)) ? SHELL_HI : SHELL_LO);
          playSdRaw1.play("roms/Battlezone/shellhi.hex");
      /*    if (val & bit(3))
            playSdWav1.play("roms/Battlezone/fire1.wav");
          else
            playSdWav1.play("roms/Battlezone/fire2.wav");*/
        }
        if (val & bit(7))
        { // motor
          //  disable_sound(MOTOR_HI);
          //  disable_sound(MOTOR_LO);
          // enable_sound((val & bit(4)) ? MOTOR_HI : MOTOR_LO);
       /*   if (val & bit(4))
            playSdWav1.play("roms/Battlezone/motor_slow_mono.wav");
          else
            playSdWav1.play("roms/Battlezone/motor_fast.wav");*/
        }

        // execute a function here to flash LEDs
        break;
      case MBSTART:
        /* printf("@%04x MBSTART wr addr %04x val %02x\n", PC, addr & 0x1f, val); */
        mb_go(addr & 0x1f, val);
        break;
      case IGNWRT:
        break;
      case ROMWRT:
        break;
      case UNKNOWN:
        break;
      default:
        break;
    }
  }
}

// Bzone audio support

const int16_t explode_lo[] = {
  // #include "expLo.hex"
};
const int16_t explode_hi[] = {
  //#include "expHi.hex"
};
const int16_t shell_lo[] = {
  //#include "shellLo.hex"
};
const int16_t shell_hi[] = {
  //#include "shellHi.hex"
};
const int16_t motor_lo[] = {
  //#include "motorLo.hex"
};
const int16_t motor_hi[] = {
  //#include "motorHi.hex"
};
// Pokey sounds:
// {1 radar,  2 bump,  4 blocked,  8 extra life,  0x10 enemy appears,  0x20 saucer hit,  0x40 short saucer sound,  0x80 high score melody}
const int16_t radar[] = {
  //#include "radar.hex"
};
const int16_t bump[] = {
  //#include "bump.hex"
};
const int16_t blocked[] = {
  //#include "blocked.hex"
};
const int16_t life[] = {
  //#include "life.hex"
};
const int16_t enemy[] = {
  //#include "start.hex"
};
const int16_t saucer_hit[] = {
  //#include "saucerhit.hex"
};
const int16_t saucer[] = {
  //#include "saucer.hex"
};
const int16_t high_score[] = {
  //#include "hiscore.hex"
};
const int16_t smart[] = {
  //#include "smart.hex"
};

// Add this to the mix

typedef struct _sound_rec {
  const int16_t *ptr;
  uint32_t len; // Len of the sample after processing
  uint32_t idx; // Curr index into the sample.
  uint32_t oneshot; // When 1 don't repeat
} sound_rec;

sound_rec sounds[] = {
  { 0, 0, 0, 0 },
  { explode_lo, 0, 0, 1},
  { explode_hi, 0, 0, 1 },
  { shell_lo, 0, 0, 1 },
  { shell_hi, 0, 0, 1 },
  { motor_lo, 0, 0, 0 },
  { motor_hi, 0, 0, 0 },
  { smart, 0, 0, 1},
  { radar, 0, 0, 1 },
  { bump, 0, 0, 1},
  { blocked, 0, 0, 1},
  { life, 0, 0, 1},
  { enemy, 0, 0, 1},
  { saucer_hit, 0, 0, 1},
  { saucer, 0, 0, 1},
  { high_score, 0, 0, 1}
};

void add_sounds()
{
  uint i;
  uint32_t len;
  uint32_t p;

  for (i = 0; i < sizeof(sounds) / sizeof(sound_rec); i++)
  {
    p = (uint32_t)sounds[i].ptr;

    if (p)
    {
      len = REG32(p + 0x28);
      len /= 2; // Len in 16bit samples
      len += AUDACITY_WAV_HDR_OFF;
      sounds[i].len = len;
      sounds[i].idx = AUDACITY_WAV_HDR_OFF;
    }
  }
}

void enable_sound(uint32_t mask)
{
  g_aud_smask |= mask;
}

void disable_sound(uint32_t mask)
{
  g_aud_smask &= ~mask;
}

void start_sample(uint32_t mask)
{
  // {1 radar,  2 bump,  4 blocked,  8 extra life,  0x10 enemy appears,  0x20 saucer hit,  0x40 short saucer sound,  0x80 high score melody}
  if (mask)
    g_aud_smask |= (mask << 8);
}
/*
  int16_t get_sample()
  {
  uint32_t i;
  int16_t worklist[16];
  uint16_t idx = 0;
  int16_t mixer(int16_t *dat, uint16_t factor, uint32_t n);

  if (0 == g_aud_enable)
    return 0;

  for (i = 1; i < sizeof(sounds) / sizeof(sound_rec); i++)
  {
    if (g_aud_smask & bit(i))
    {
      worklist[idx++] = sounds[i].ptr[sounds[i].idx];
      sounds[i].idx++;

      if (sounds[i].idx == sounds[i].len)
      {
        sounds[i].idx = AUDACITY_WAV_HDR_OFF;

        if (sounds[i].oneshot)
          g_aud_smask &= ~bit(i);
      }
    }
  }

  if (idx == 1)
    return worklist[0];
  else
    return mixer(worklist, 32768 / idx, idx << 1);
  }
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

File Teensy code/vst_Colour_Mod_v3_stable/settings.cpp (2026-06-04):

/*
   VSTCM

   Vector Signal Transceiver Colour Mod using MCP4922 DACs on the Teensy 4.1

   Code to read and write settings to SD card and draw menus on screen

*/

#include "main.h"

#ifdef VSTCM
#include <SD.h>
#else
#pragma warning(disable : 4996)  // Get rid of annoying compiler warnings in VC++
#include <cstring>
#include <stdlib.h>
#endif

#include "settings.h"
#include "drawing.h"

char gMsg[50];  // Optional additional information to show on menu

// Cached vectors for test patterns: may be better to generate these dynamically
// to avoid using memory
static DataChunk_t Chunk[NUMBER_OF_TEST_PATTERNS][MAX_PTS];
static int nb_points[NUMBER_OF_TEST_PATTERNS];
//
// Settings menu
//
int sel_setting;  // Currently selected menu choice

params_t v_setting[2][NB_SETTINGS] = {
  { 
    { "TEST_PATTERN", "RGB test patterns", 0, 0, 4, 0 },
    { "OFF_SHIFT", "Beam transit speed", OFF_SHIFT, 0, 50, 0 },
    { "OFF_DWELL0", "Beam settling delay", OFF_DWELL0, 0, 50, 0 },
    { "OFF_DWELL1", "Wait before beam transit", OFF_DWELL1, 0, 50, 0 },
    { "OFF_DWELL2", "Wait after beam transit", OFF_DWELL2, 0, 50, 0 },
    { "NORMAL_SHIFT", "Drawing speed", NORMAL_SHIFT, 1, 255, 0 },
    { "FLIP_X", "Flip X axis", FLIP_X, 0, 1, 0 },
    { "FLIP_Y", "Flip Y axis", FLIP_Y, 0, 1, 0 },
    { "SWAP_XY", "Swap XY", SWAP_XY, 0, 1, 0 },
    { "SHOW DT", "Show DT", SHOW_DT, 0, 1, 0 },
    { "PINCUSHION", "Pincushion adjustment", PINCUSHION, 0, 1, 0 },
    { "IR_RECEIVE_PIN", "IR receive pin", IR_RECEIVE_PIN, 0, 54, 0 },
    { "AUDIO_PIN", "Audio pin", AUDIO_PIN, 0, 54, 0 },
    { "NORMAL1", "Normal text brightness", NORMAL1, 0, 255, 0 },
    { "BRIGHTER", "Highlighted text brightness", BRIGHTER, 0, 255, 0 },
    { "SERIAL_WAIT_TIME", "Test pattern delay", SERIAL_WAIT_TIME, 0, 255, 0 },
    { "COLOUR_SWITCH", "Colour / Monochrome display", COLOUR_SWITCH, 0, 1, 0 },
    { "UNUSED", "Unused", 0, 0, 1, 0 },
    { "UNUSED", "Unused", 0, 0, 1, 0 },
    { "UNUSED", "Unused", 0, 0, 1, 0 },
    { "UNUSED", "Unused", 0, 0, 1, 0 },
    { "UNUSED", "Unused", 0, 0, 1, 0 },
    { "UNUSED", "Unused", 0, 0, 1, 0 },
    { "UNUSED", "Unused", 0, 0, 1, 0 },
    { "UNUSED", "Unused", 0, 0, 1, 0 },
    { "UNUSED", "Unused", 0, 0, 1, 0 },
    { "UNUSED", "Unused", 0, 0, 1, 0 },
    { "UNUSED", "Unused", 0, 0, 1, 0 },
    { "UNUSED", "Unused", 0, 0, 1, 0 },
    { "UNUSED", "Unused", 0, 0, 1, 0 },
  },
  { 
    { "SETTINGS", "Settings", 0, 0, 0, settings },
    { "asteroids", "Asteroids", 0, 0, 0, emu_vecsim },
    { "deluxe", "Asteroids Deluxe", 0, 0, 0, emu_vecsim },
    { "blackwidow", "Black Widow", 0, 0, 0, emu_vecsim },
    { "battlezone", "Battlezone", 0, 0, 0, emu_vecsim },
    { "gravitar", "Gravitar", 0, 0, 0, emu_vecsim },
    { "lunar", "Lunar Lander", 0, 0, 0, emu_vecsim },
    { "majorhavoc", "Major Havoc", 0, 0, 0, emu_vecsim },
    { "quantum", "Quantum", 0, 0, 0, emu_vecsim },
    { "redbaron", "Red Baron", 0, 0, 0, emu_vecsim },
    { "spaceduel", "Space Duel", 0, 0, 0, emu_vecsim },
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

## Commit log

2022-05-14 Update BOM teensyv.txt
2022-05-19 Delete teensyv-sch.pdf
    Deleted v2 to replace with v2.1 which has a corrected symbol and connections for U5.
2022-05-19 Add files via upload
    v2.1 has a corrected symbol and connections for U5.
    [teensyv.kicad_pcb, teensyv.kicad_sch]
2022-05-19 Add files via upload
    v2.1 with corrected pin order for U5.
    [teensyv-B_Cu.gbr, teensyv-B_Mask.gbr, teensyv-B_Paste.gbr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]
2022-05-28 Update BOM teensyv.txt
    U4 is no longer needed and should be jumpered
2022-06-06 repair build when IR_REMOTE is disabled. fix a few warnings.
    [vst_Colour_Mod_v2_Teensy_41.ino]
2022-06-06 Update README.md
    Simplified power options using a table
2022-06-29 Update vst_Colour_Mod_v2_Teensy_41.ino
    Added debounce routines for the control buttons, plus minor optimisations
2022-06-30 Update vst_Colour_Mod_v2_Teensy_41.ino
    Writing settings to the SD card now works. Use the centre button or OK on the IR remote to save settings.
2022-07-15 Update vst_Colour_Mod_v2_Teensy_41.ino
    Incorporating speed mods developed by fcawth (no hardware changes required to PCB v2 at this point)
2022-07-15 Rename BOM teensyv.txt to BOM/BOM vstcm v2.txt
    File moved and renamed explicitly to v2 in anticipation of v3
2022-07-15 Moved to v2 directory
    [teensyv.kicad_pcb, teensyv.kicad_sch]
2022-07-18 Update vst_Colour_Mod_v2_Teensy_41.ino
    Incorporating mods made by fcawth: improvements to AdvanceMAME handshake, tweaks to default settings values, beam settling delay handled better, button management shifted to end of main loop to prevent bright spot appearing, beam transit shifted to end of brightness function
    [vst_Colour_Mod_v2_Teensy_41.ino]
2022-08-29 Reorganise folders and archive V2
    [teensyv-B_Cu.gbr, teensyv-B_Mask.gbr, teensyv-B_Paste.gbr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]
2022-08-29 Update with V3 schematic and code
    [vstcm V3_0FC-B_Cu.gbr, vstcm V3_0FC-B_Mask.gbr, vstcm V3_0FC-B_Paste.gbr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]
2022-08-30 Generation of Gerber files
    [vstcm V3_0FC-B_Cu.gbr, vstcm V3_0FC-B_Mask.gbr, vstcm V3_0FC-B_Paste.gbr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]
2022-09-03 Spot killer adjustment and tuning
    The spot killer moves will now happen if there is enough time in the frame, even if the min and max are in range. This keeps the spot killer on the newer 6100s and repros (most sensitive) from trigge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
2022-09-04 Fixed IR Remote code
    IR remote define was in the vst_color_Mod_V3.cpp file so it was not being seen by buttons.cpp so the remote did not work. Moved the remote -related code to the relevant files
    [settings.h]
2022-10-06 Update README.md
    Added 6th power option: external 5V regulated supply
2022-10-17 Add files via upload
    Added document describing changes required to convert PCB V2 DAC outputs to V3
2022-12-04 Added Vector Donkey Kong running on MAME on the Teensy
2023-03-28 Added debug for Windows
    New version of code which can be compiled for Teensy or Windows to facilitate debugging
2024-01-21 Updated U3 from 5V to 3.3V
    Corrected U3 LP2950 requires a 3.3V output instead of 5V
2024-01-21 Animated vector fonts is a demo
    [vstcm V3_0FC.kicad_pcb]
2024-02-01 Added a guide to programming the Teensy with code for VSTCM
    Added a guide to programming the Teensy with code for VSTCM
2024-09-04 Update BOM vstcm v3.txt
    Add part numbers for some resistors that were missing.
2024-09-06 Added Teensy and deleted inductor L1
2024-09-06 Added IC sockets
2024-09-07 More info on type of IC sockets and mounting for Teensy; Kicad files updated to v8.
    [vstcm V3_0FC.kicad_pcb, vstcm V3_0FC.kicad_sch]
2025-01-20 Various extra comments added to the code
    [vstcm V3_0FCMod of V2.kicad_sch]
2025-04-09 Added that U5 needs to be bridged if powering everything from USB
    Added that U5 needs to be bridged if powering everything from USB
2025-04-11 Corrected bug to make settings buttons work when playing a game over USB
    [main.cpp]
2025-06-05 Fix for compiler error
    Fix for compiler error
    [main.cpp]
2025-07-14 Power supply

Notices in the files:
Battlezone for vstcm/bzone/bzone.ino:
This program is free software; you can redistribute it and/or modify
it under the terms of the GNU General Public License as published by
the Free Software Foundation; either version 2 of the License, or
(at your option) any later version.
